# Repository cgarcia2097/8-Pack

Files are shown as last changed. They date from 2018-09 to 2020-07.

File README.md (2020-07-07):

# 8-Pack

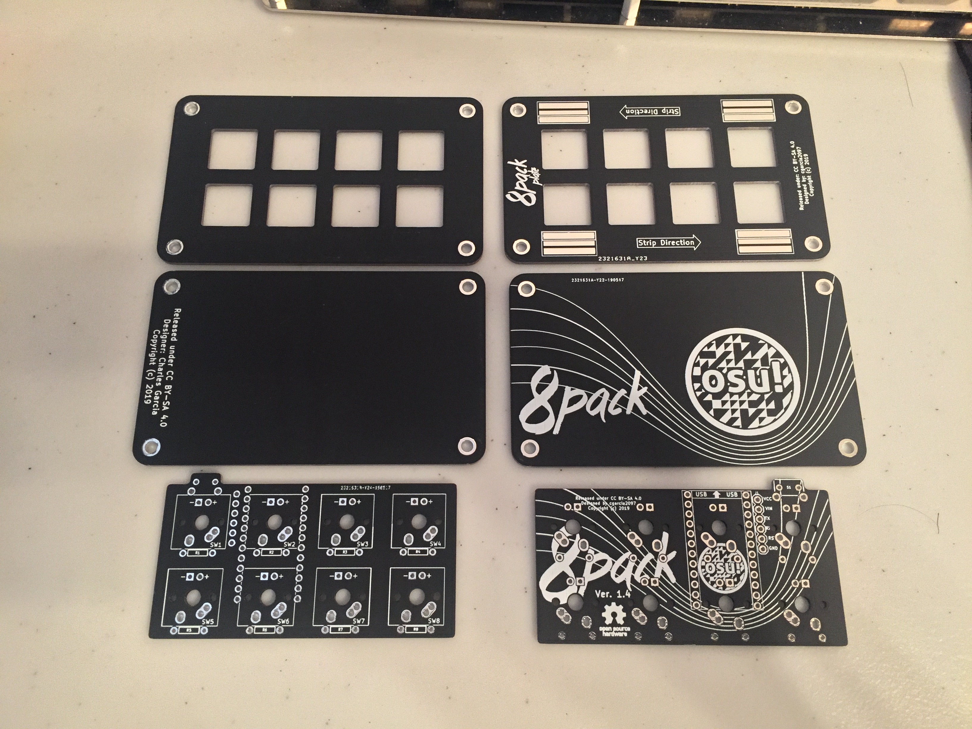
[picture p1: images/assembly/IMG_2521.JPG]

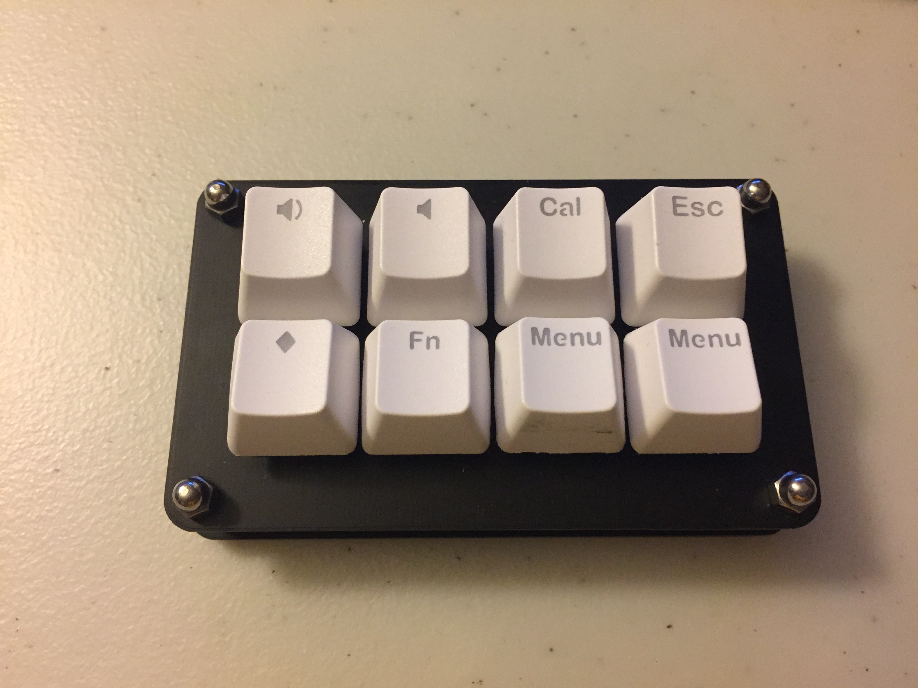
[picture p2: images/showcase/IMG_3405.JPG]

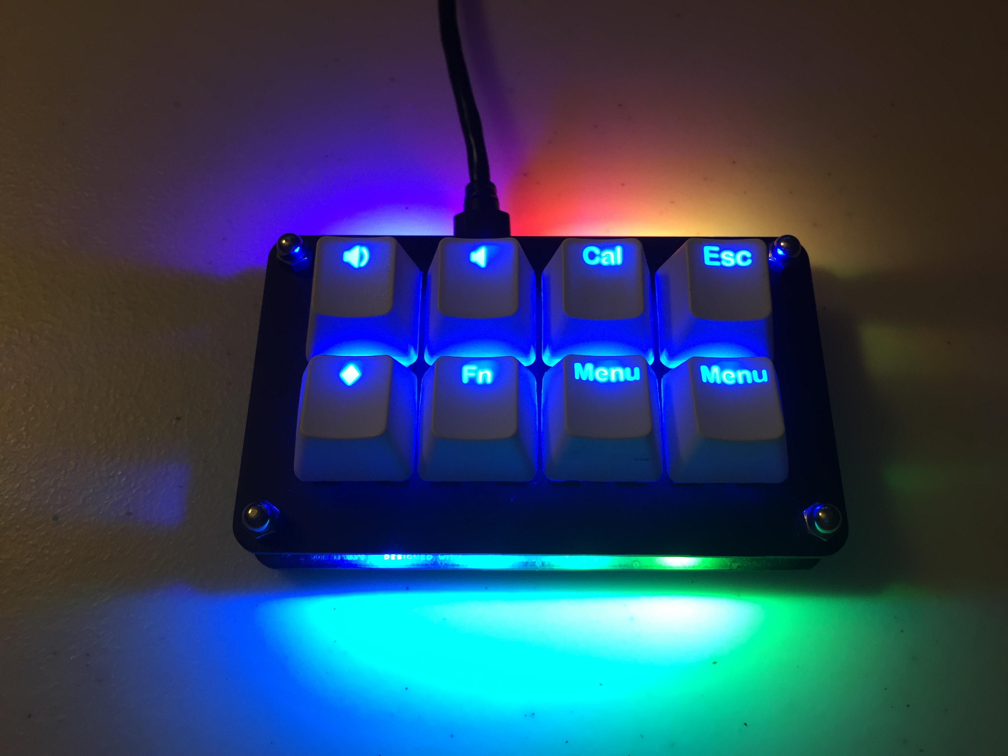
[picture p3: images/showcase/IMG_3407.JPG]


Inspired by [di0ib's Six Pack design](http://www.40percent.club/2017/04/six-pack-10.html), this keypad project is intended for me on learning how to use KiCAD by extending their design to 8 keys. Mishaps, snafus and foobars expected and incoming.

## Features

### PCB

  - 8 keys, directly connected to MCU pins
  - 8 backlight LEDs, individually addresssable
  - Powered by the Pro Micro
  - Alps or MX button support
  - Runs on a simple Arduino sketch, or optionally QMK firmware

### Plates
  - WS2812 strip underglow support, inspired by [di0db's Gherkin ALPS underglow](http://www.40percent.club/2017/08/gherkin-alps-11.html)

## Third-party firmware ports

- Official QMK port, courtesy of [gorbachev](https://github.com/gorbachev)
  - Rev. 1.1 : [Link](https://github.com/qmk/qmk_firmware/tree/master/keyboards/8pack/rev11)
  - Rev. 1.2 : [Link](https://github.com/qmk/qmk_firmware/tree/master/keyboards/8pack/rev12)

## Assembly guides

Assembly guide can be found here: [GUIDE](ASSEMBLY.md)

## Programming guides

Programming guide can be found here: [GUIDE](PROGRAMMING.md)

## Updates

Updates are posted here: [UPDATES](UPDATES.md)

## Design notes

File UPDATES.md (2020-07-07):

# Update 07/06/2020

It's been three months since the last update, and other projects have been on my mind lately. I am updating this repo as a change of pace, and here's the recent set of updates:

## Added to the repo
* Updated [programming guide](./ASSEMBLY.md)
* Added [more images](./images/showcase/)
* Updated [README](./README.md) page

## TBD
* QMK port for Rev. 1.4 - 1.5
* Choosing a mainline 8pack revision, since maintaining all other revisions seem redundant

# Update 04/02/2020

Whew, it's been almost a year. Finally got back into updating the repos as usual

## Added to the repo
* Updated [assembly guide](./ASSEMBLY.md)
* Updated directory structure for code, keypad and plate files

## Removed from the repo
* Redundant images and links
* KiCAD symbols and footprints (To be released as a seperate repository)
* Old assembly guide

## TODO
* Updated programming guide
* Ordering guide

# Update 04/20/2019
Did some repo cleaning and added Ver. 1.2 of the keypad PCB. I am currently considering creating seperate directories for the plate and keypad PCBs sice they both have their own revisions. I have uploaded assembly images involving the Ver. 1.2 PCB, and will be added to the assembly guide.

TODO:
* Seperate keypad, plate and source code directories
* Fix the keypad libraries uploaded
* Complete the assembly guide
* Complete programming guide

# Update 04/17/2019
I have created a skeleton guide for assembling the 8pack. The order of steps are important since backtracking the steps requires knowledge of desoldering. The guide itself is still a WIP.

Current assembly guide: ASSEMBLY GUIDE

# Update 03/29/2019
Thought I would try doing PCB plates for the keypad. So I whipped up a quick design on KiCAD that integrates LED strips facing downwards from the PCB. 

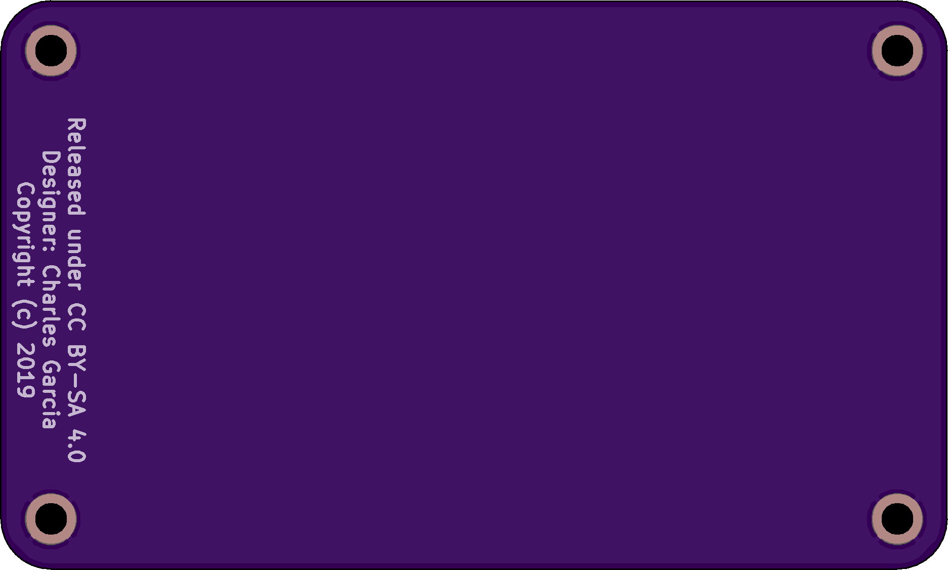
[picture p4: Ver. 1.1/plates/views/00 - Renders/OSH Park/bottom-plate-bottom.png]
bottom-plate-bottom

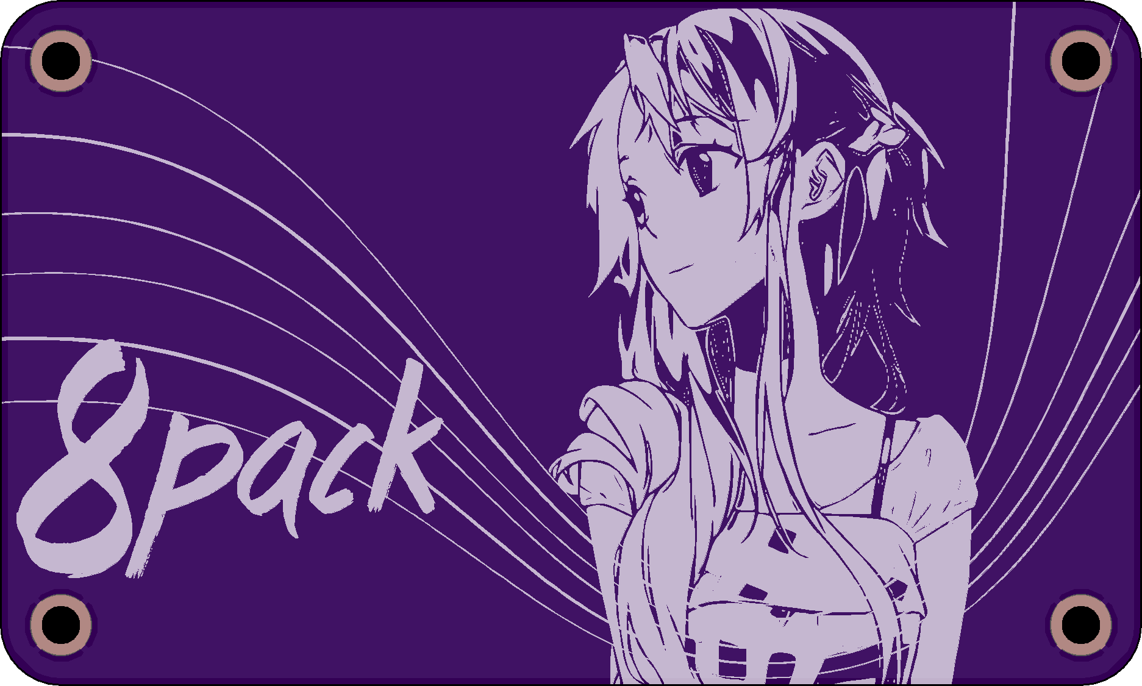
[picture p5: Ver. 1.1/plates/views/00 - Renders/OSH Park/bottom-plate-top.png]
bottom-plate-top

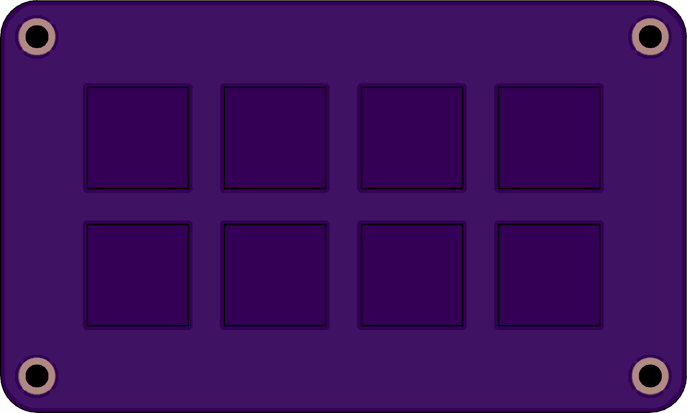
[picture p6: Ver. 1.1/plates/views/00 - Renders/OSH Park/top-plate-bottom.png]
top-plate-bottom

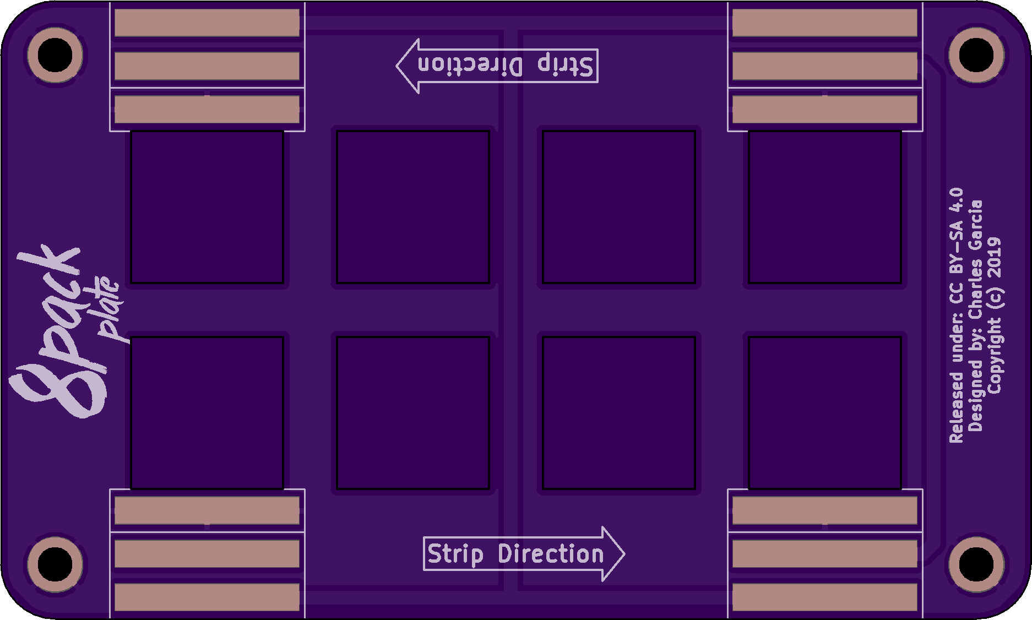
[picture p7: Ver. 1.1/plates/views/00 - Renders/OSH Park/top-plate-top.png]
top-plate-top


The plates have arrived from JLCPCB, and the results are as follows:

* The square cutouts are rounded, but still allow for the fitting of Cherry-style switches. I used di0ib's Six-Pack plate as inspiration.

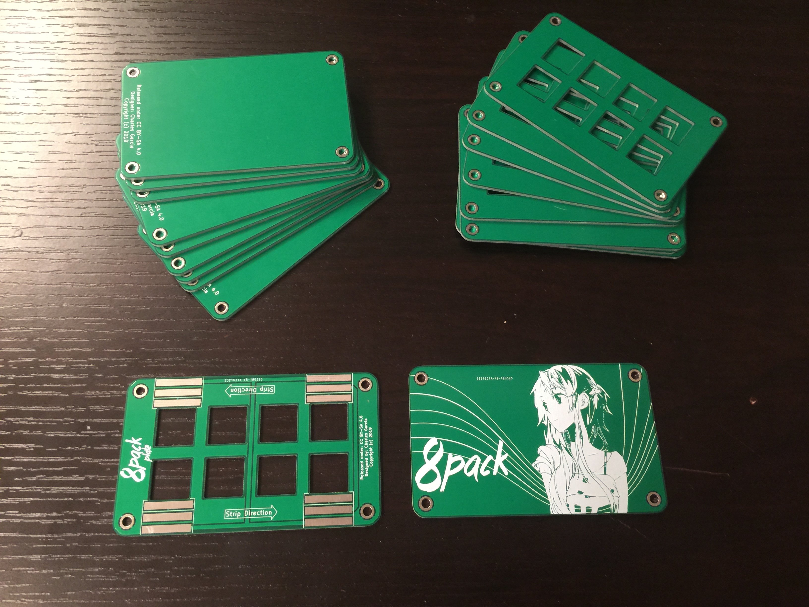
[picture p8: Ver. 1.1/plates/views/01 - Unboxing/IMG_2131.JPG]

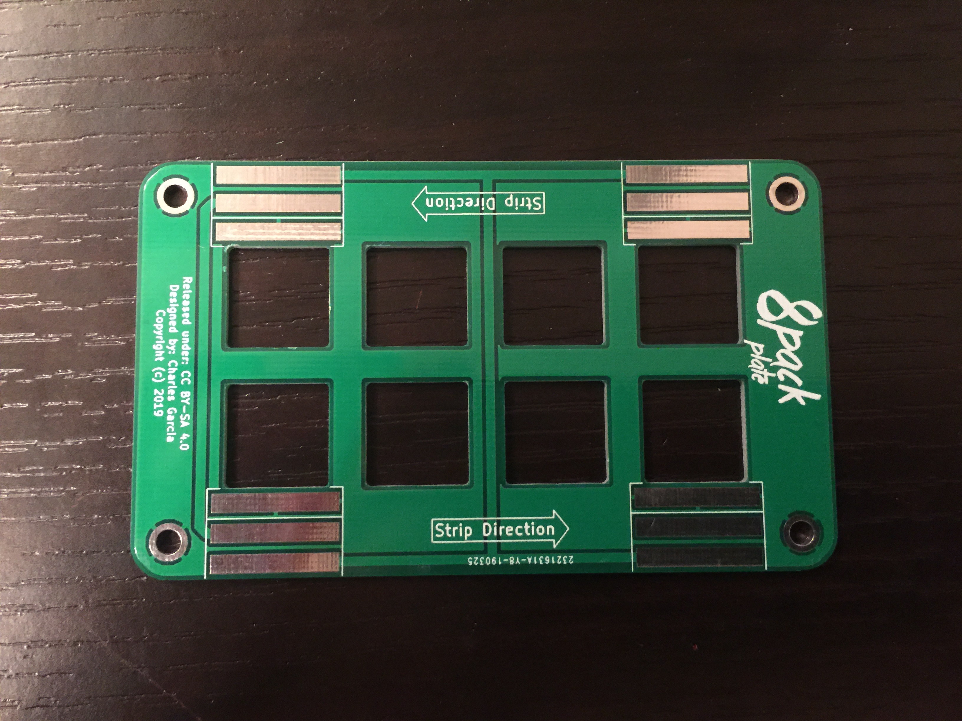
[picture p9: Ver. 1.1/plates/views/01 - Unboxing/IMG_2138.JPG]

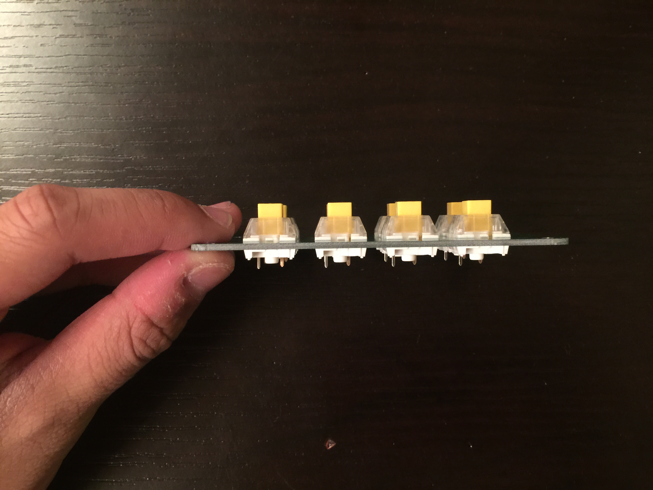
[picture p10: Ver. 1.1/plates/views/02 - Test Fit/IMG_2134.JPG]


* The LED pads are misaligned with the LED strip I used. Guess I need to re-measure those LED pads once more so they are easier to solder together. In the meantime, I used an old-fashioned solder bridge to do the job. In the end the lighting circuit worked.

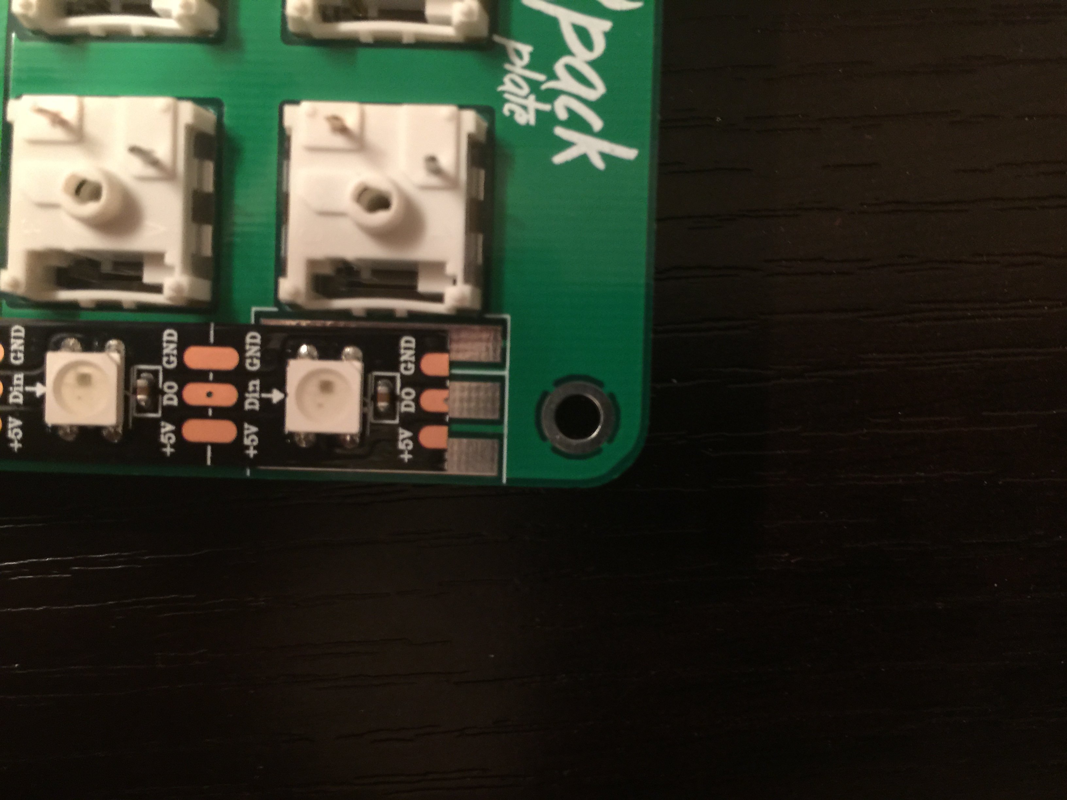
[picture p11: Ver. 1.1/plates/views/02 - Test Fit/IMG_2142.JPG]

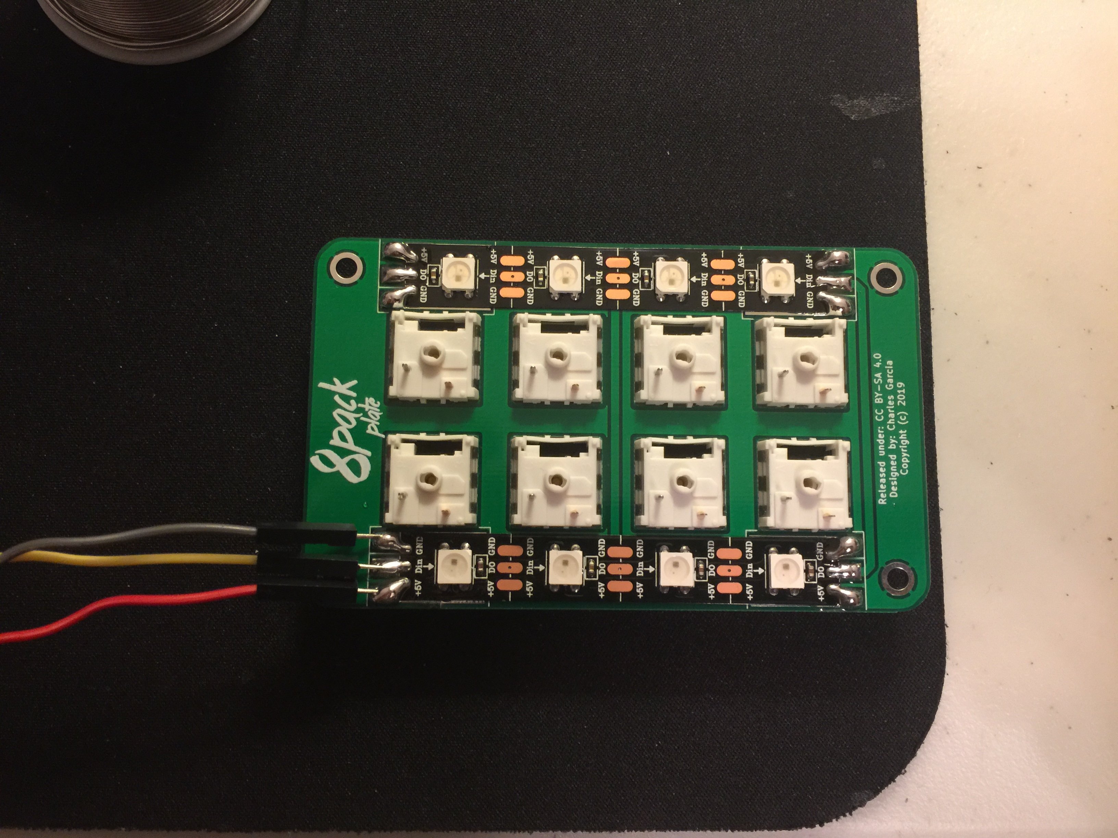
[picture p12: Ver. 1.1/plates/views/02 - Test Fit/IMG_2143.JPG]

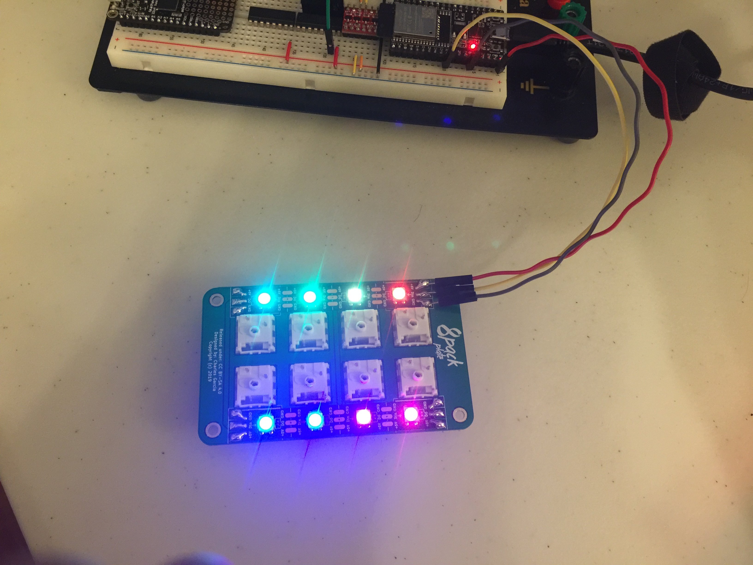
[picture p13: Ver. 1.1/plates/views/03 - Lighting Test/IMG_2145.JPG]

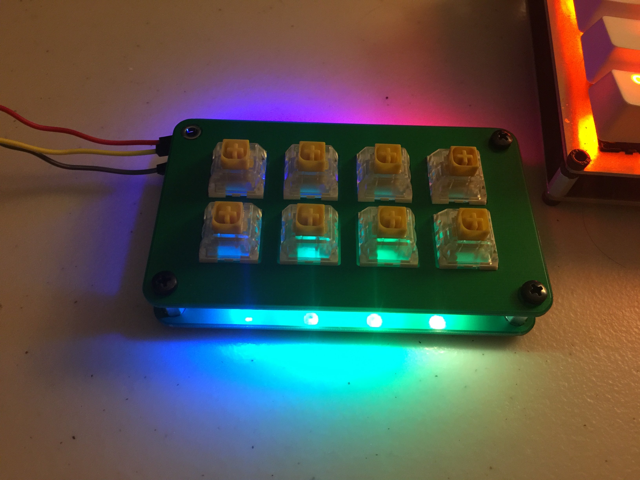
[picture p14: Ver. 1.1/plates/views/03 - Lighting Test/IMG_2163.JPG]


* PCB material is tough. No wonder other KBDers use them in budget builds and kits.

### More images in this link Please enjoy :)

TODO: 
* Assembly guides
* Post photos and format accordingly
* Firmware guides
* Other repo cleanup

# Update 02/20/2018
I decided to take a detour and learn KiCAD for version 1.1 of the PCB. As such, the design files uploaded are now in the KiCAD format. Gerbers, PCB files and schematics are now available for use and scrutiny.

The PCBs have arrived from JLCPCB and tested with a multimeter. Arduino sketch has also been tested on the board to verify basic funtionality.

Fixes:
* RESET and GND are no longer shorted. 
* The Pro Micro has been re-oriented so that the user no longer is required to use sockets to elevate it. Simple male headers will suffice

To-do:
* Assembly/Programming guide
* Upload footage of assembly and programming guide.

## Photos
#### Front
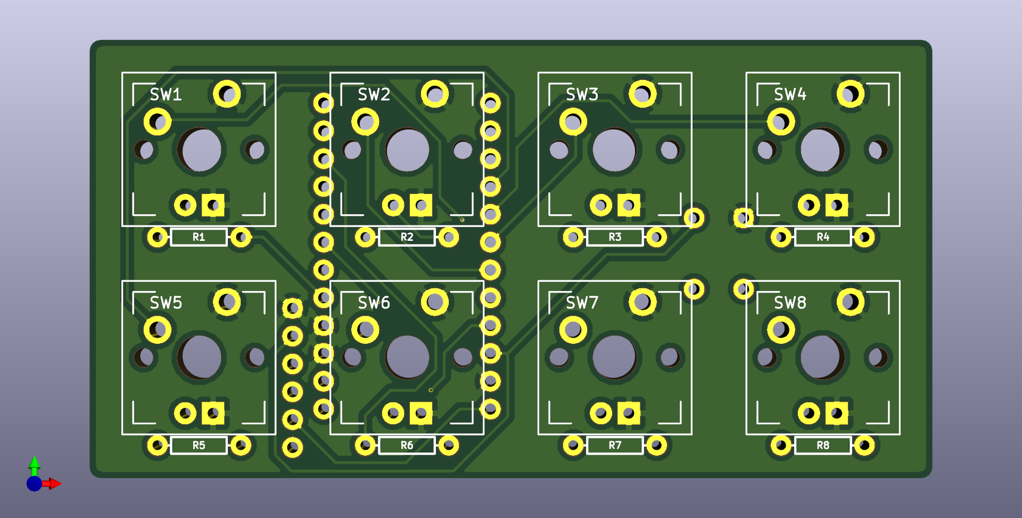
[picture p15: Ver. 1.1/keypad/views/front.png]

#### Back
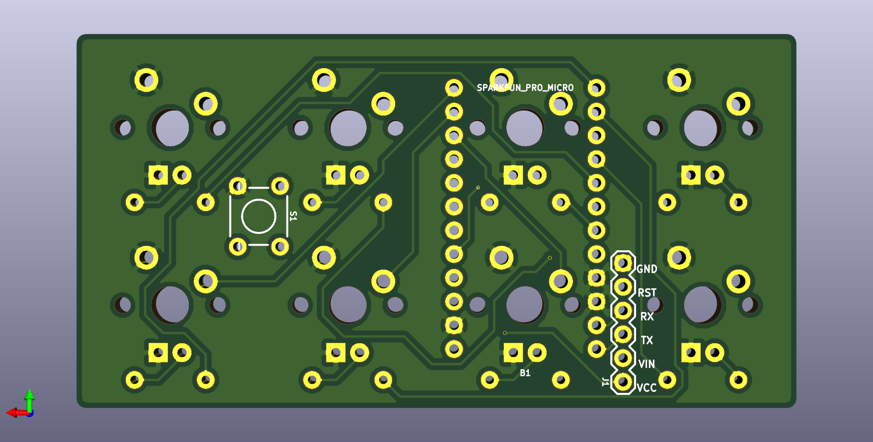
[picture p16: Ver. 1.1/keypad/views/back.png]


# Update 09/27/2018
First batch of PCBs have arrived from Aisler. I am happy to report that the PCBs are of high quality, as well as my footprints being correct and accurate. The parts fit together like a charm. 

Unfortunately, the existing gerbers on the repo exhibit issues discussed below:

- RESET and GND are shorted for some reason. Verified with a continuity check for the entire batch. Must be my fault since they are short for all three. Just don't connect anything to the RST header on the Pro Micro, and it should work.

- The USB port on the Pro Micro touches switch #7's contacts, and interferes with the operation. Current workaround is to use a machine socket to hold the Pro Micro in place. See di0ib's use of sockets here: http://www.40percent.club/2017/04/six-pack-10.html

Otherwise I am happy to report that the keyboard is mostly functional and ready to rock some Arduino code. Will be posting footage on my youtube channel when time permits.

# Some info
- Key Unit Size: 19 mm 

###### Board
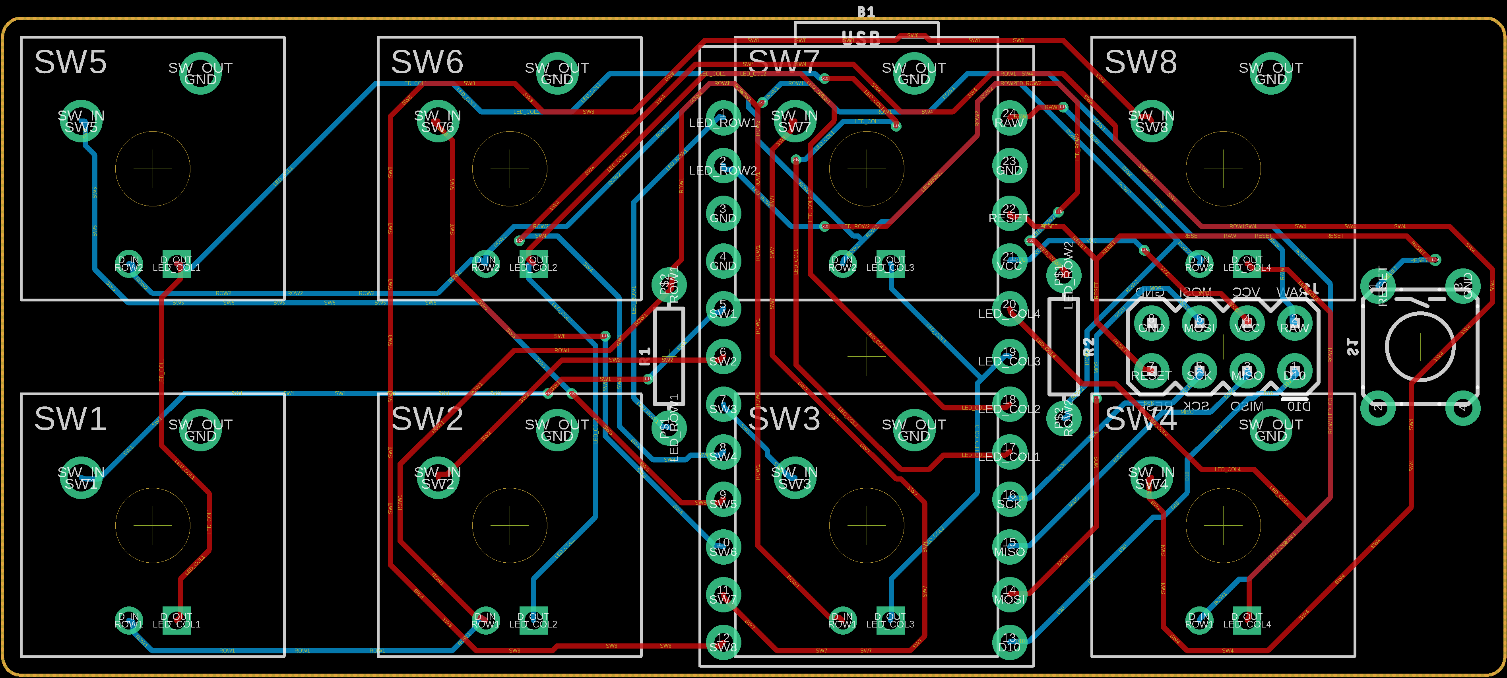
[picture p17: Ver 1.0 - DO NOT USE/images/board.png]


###### Schematic


If using swillkb's plate editor don't forget to set the unit size to 19 mm. Otherwise, the centers of each switch are 19 mm apart

# Photos
###### Lighting
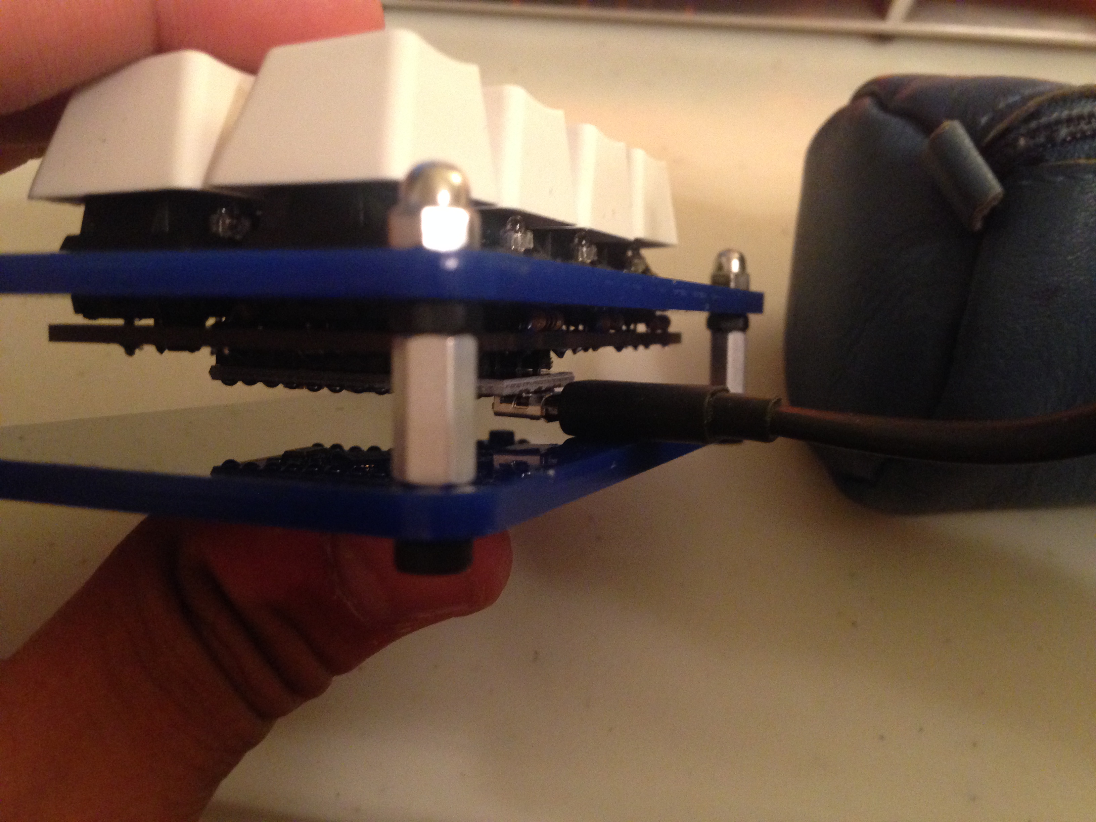
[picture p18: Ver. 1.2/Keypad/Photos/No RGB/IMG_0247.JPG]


###### Pro Micro Attached


###### Back Side


###### Front Side


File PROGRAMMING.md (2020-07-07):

# Programming Guide for 8pack
This guide will go through the method of flashing default firmware into the 8pack using the Arduino environment. Other methods are under consideration at the moment. 

### 1 - Download the required software

- Download and install the Arduino IDE from the Arduino website. ( [Link](https://www.arduino.cc/en/Main/Software) )
- Click `Install` through all the driver download prompts.
- Click `Close` when finished.

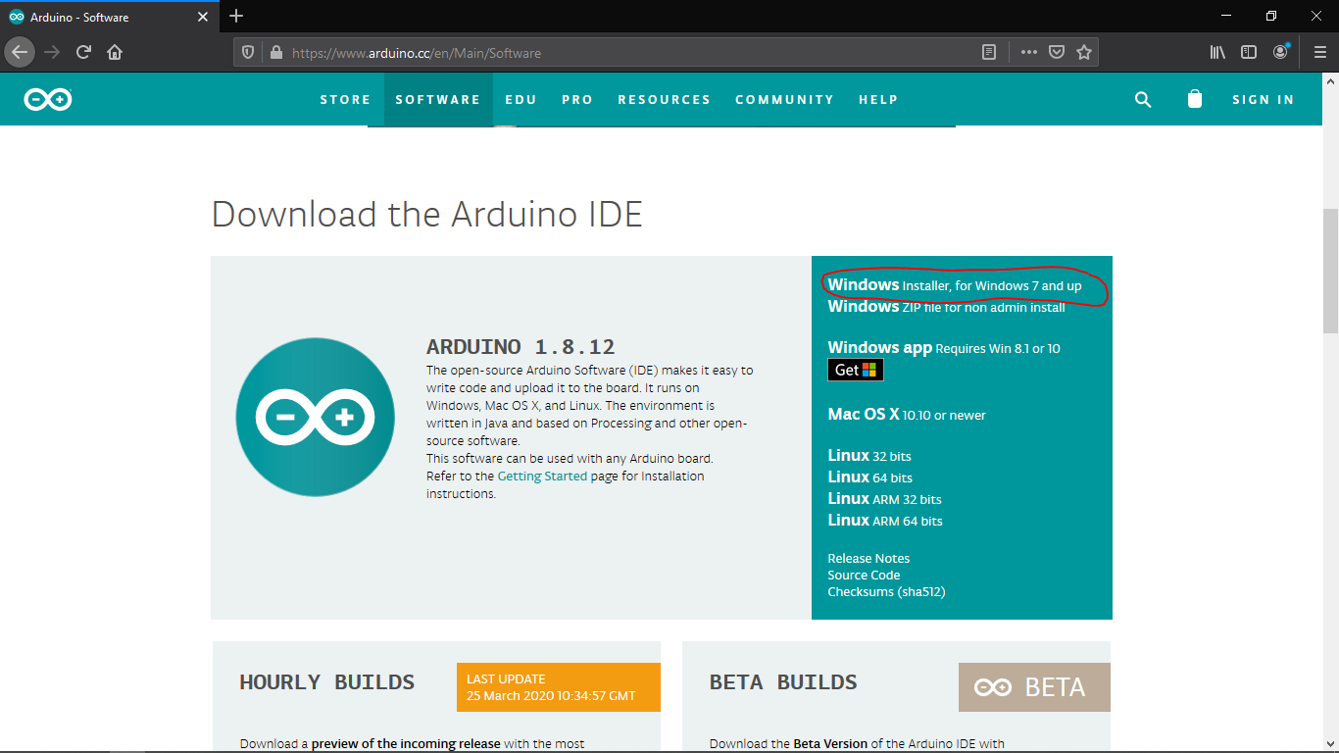
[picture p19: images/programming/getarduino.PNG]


### 2 - Get the code from the repository

- Download and unpack the project: https://github.com/cgarcia2097/8-Pack/archive/master.zip. 
- Inside Arduino, click `File`->`Open`
  
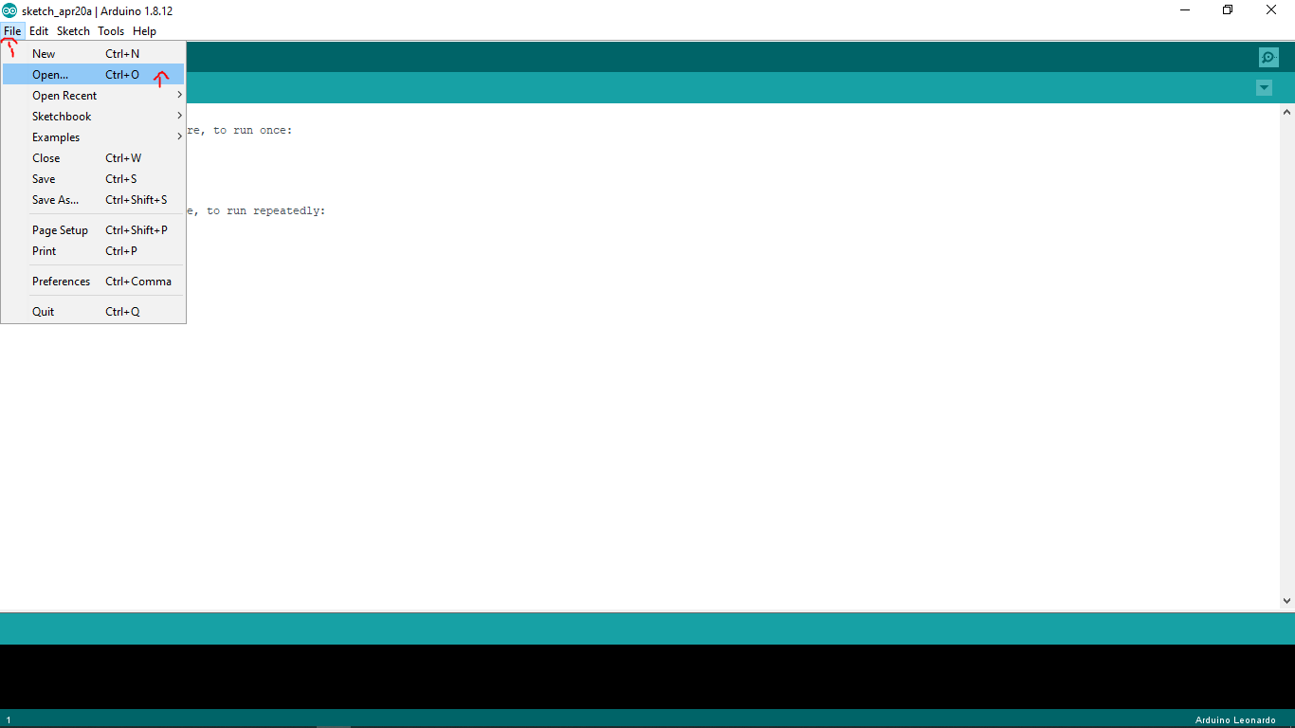
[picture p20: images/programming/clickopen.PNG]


- Find and open the newly-extracted `8-Pack` folder in Arduino
  
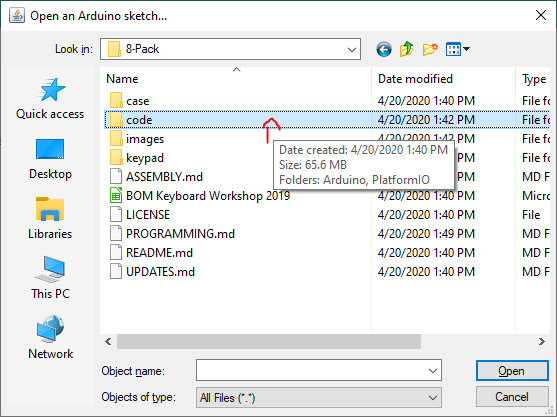
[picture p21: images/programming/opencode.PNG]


- Inside the folder, go to `code`->`Arduino`->`8pack`->`8pack.ino`.

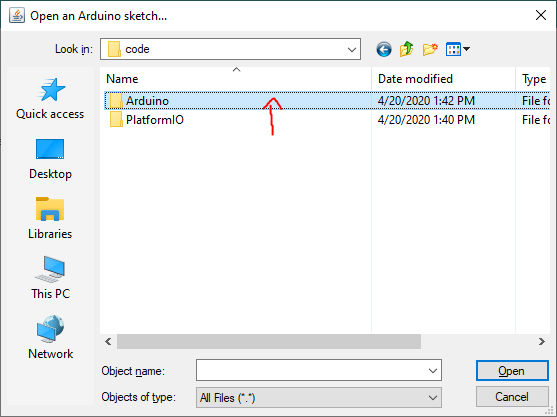
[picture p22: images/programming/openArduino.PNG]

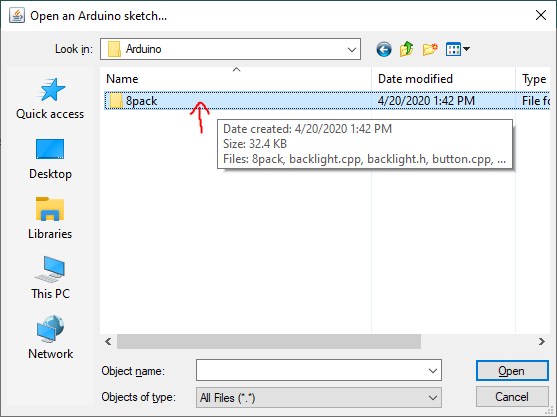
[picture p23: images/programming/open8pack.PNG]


- Open `8pack.ino`

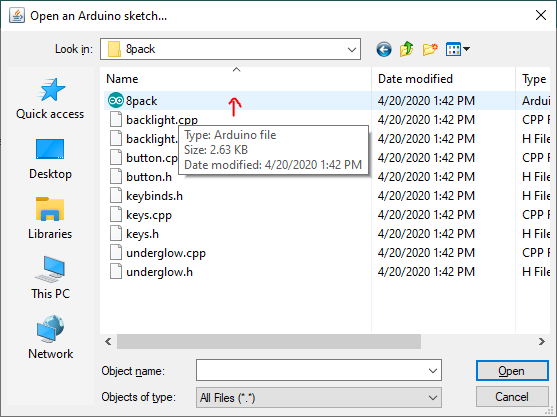
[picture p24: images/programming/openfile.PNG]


### 3 - Setting up the flashing environment

The 8pack requires a specific environment at the moment to reprogram it, as no app exists at the moment.

#### 3.1 - Installing the Libraries

Once installed, download the required libraries by clicking `Sketch`->`Include Library`->`Manage Libraries` and install these libraries:
  - Adafruit Neopixel
  - Bounce2

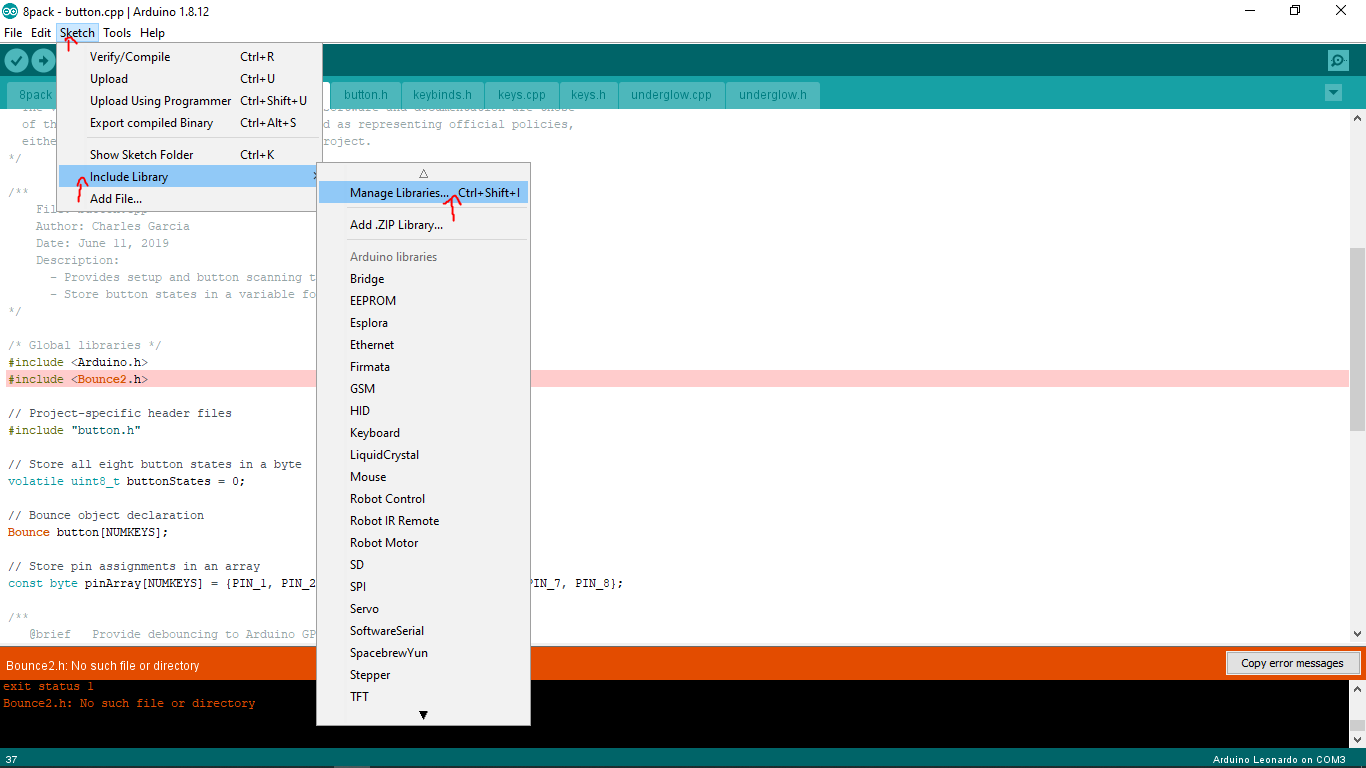
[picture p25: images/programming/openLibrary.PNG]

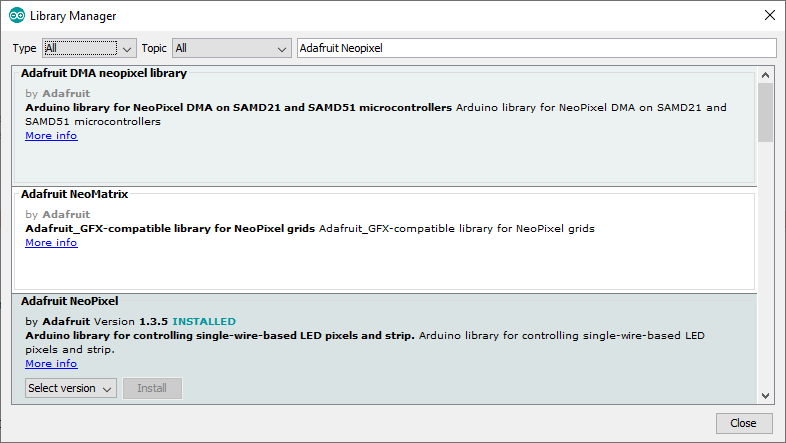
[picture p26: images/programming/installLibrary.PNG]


#### 3.2 - Programming for the Pro Micro

To set the environment to program for a Pro Micro, click `Tools`->`Board`->`Arduino Leonardo`. 

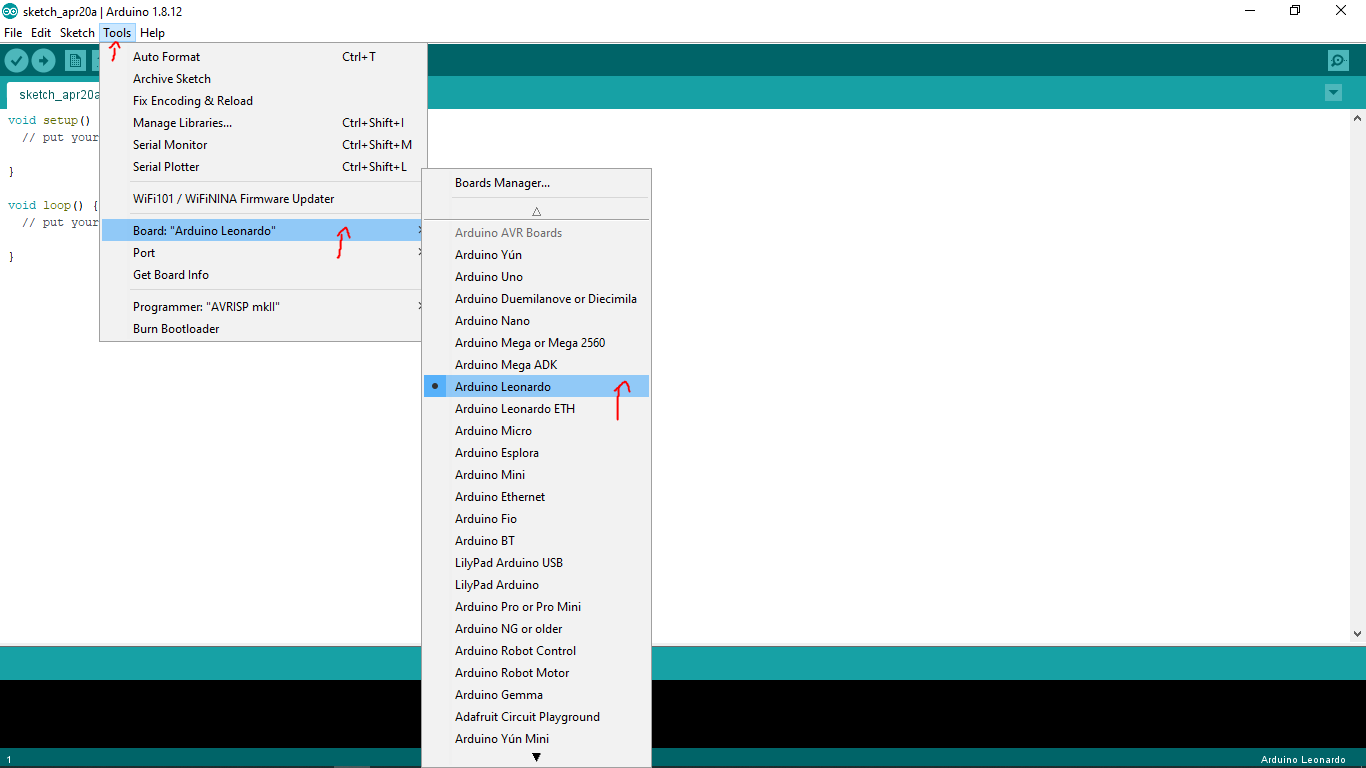
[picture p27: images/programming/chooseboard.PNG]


While the Pro Micro has its own [installation guide](https://learn.sparkfun.com/tutorials/pro-micro--fio-v3-hookup-guide/all), it seems to share the same pin labels as the Arduino Leonardo. Choosing the Leonardo allows us to skip the hassle of setting up the Pro Micro manually, but may be subject to change later down the line as Sparkfun may change their design.

### 4 - Editing the keybinds

Click over to the tabs and select `keybinds.h`



You will see a large block of text that looks like this:
``` 
const unsigned char macroArray[NUMKEYS][HID_USB_LIMIT] = {
  {KEY_ESC, STOP_CODE, STOP_CODE, STOP_CODE, STOP_CODE, STOP_CODE},
  {'d', STOP_CODE, STOP_CODE, STOP_CODE, STOP_CODE, STOP_CODE},
  {'s', STOP_CODE, STOP_CODE, STOP_CODE, STOP_CODE, STOP_CODE},
  {'a', STOP_CODE, STOP_CODE, STOP_CODE, STOP_CODE, STOP_CODE},
  {'v', STOP_CODE, STOP_CODE, STOP_CODE, STOP_CODE, STOP_CODE},
  {'c', STOP_CODE, STOP_CODE, STOP_CODE, STOP_CODE, STOP_CODE},
  {'x', STOP_CODE, STOP_CODE, STOP_CODE, STOP_CODE, STOP_CODE},
  {'z', STOP_CODE, STOP_CODE, STOP_CODE, STOP_CODE, STOP_CODE},
};
```



Each row starting from starting underneath `const unsigned char macroArray[]` corresponds to a button on the keypad.

What the keypad does is iterate through each row pressing and releasing (for when button is pressed or released) each key up until the `STOP_CODE` marker appears. This allows us to do a single press or multiple simultaneous keypresses per button.

Let's go through some examples.

- If you want to press the `Escape` key on button 1, the first row should look like:

  `{KEY_ESC, STOP_CODE, STOP_CODE, STOP_CODE, STOP_CODE, STOP_CODE},`

- If you're a little macro heavy and wanna type a six-letter word on button 5, the fifth row should look like:

  `{'m', 'a', 'n', 'n', 'e', 'r'},`

- If you like your Copy and Paste functionalities, your chosen two rows would look like this

  `{KEY_LEFT_CTRL, 'c', STOP_CODE, STOP_CODE, STOP_CODE, STOP_CODE},`

  `{KEY_LEFT_CTRL, 'z', STOP_CODE, STOP_CODE, STOP_CODE, STOP_CODE},`

Letters, numbers and symbols are typed in single quotes, while modifiers like CTRL and SHIFT must use the defined macros here: https://www.arduino.cc/en/Reference/KeyboardModifiers

### 5 - Compiling and uploading the code

- Plug the keypad into your PC.
- Click `Tools`->`Ports` and select the port with (Arduino/Genuino) beside the port name




- Click `Verify` to compile your code




- Click `Upload` to upload your code




### Testing out the keypad bindings
Open your text editor of choice and give the keys some quick presses and see if the desired keys are being shown on screen. 



### TMK/QMK support
A third-party has created a QMK port of my keypad, which can be found here: https://github.com/qmk/qmk_firmware/tree/master/keyboards/8pack

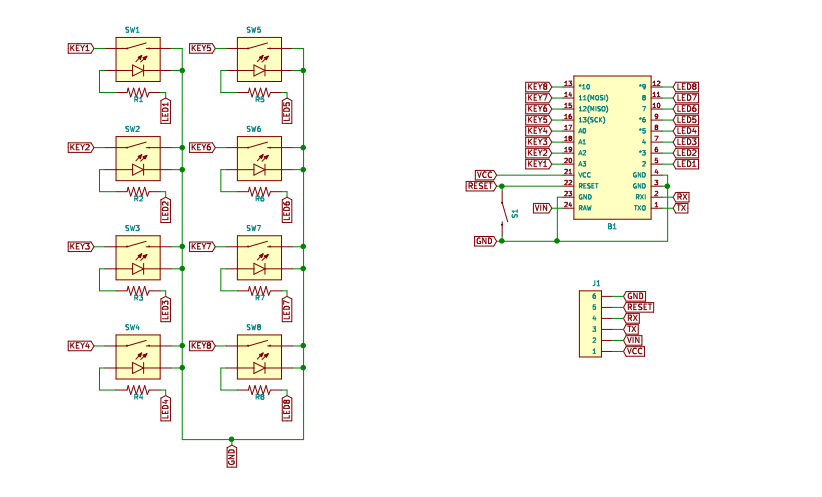
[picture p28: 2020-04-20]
images/schematic.png

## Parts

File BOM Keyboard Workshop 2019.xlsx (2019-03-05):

Part | Cost (before shipping) | Link | Unit Qty.
Pro Micro | 8.99 | https://www.amazon.ca/Pro-Micro-Atmega32u4-Arduino-Development/dp/B01N4TVIQX | 1
PCB | 2.65 | https://jlcpcb.com/quote | 10
MX-Compatible Switch | 3.18 | https://novelkeys.xyz/products/gateron-switches?variant=19441344970845 | 10
160 ohm resistor | 4.84 | https://www.digikey.ca/product-detail/en/stackpole-electronics-inc/CF14JT160R/CF14JT160RCT-ND/1830331 | 250
LED | 20 | http://www.maxkeyboard.com/max-keyboard-orange-3mm-flangeless-replacement-led-for-backlit-mechanical-keyboard-110-pcs.html | 100
Blank Keycaps | 1.32 | http://www.maxkeyboard.com/row-2-size-1x1-cherry-mx-keycap-r2-1x1.html | 1
#6 x 1/4" screws | 1.18 | https://www.homedepot.com/p/6-x-1-4-in-Phillips-Zinc-Plated-Steel-Pan-Head-Sheet-Metal-Screw-16-per-Pack-806181/204275186 | 4
Each Keyboard needs:
1 Pro Micro
8 Resistors
8 buttons
8 Keycaps
8 LEDs
1 PCB
4 Screws

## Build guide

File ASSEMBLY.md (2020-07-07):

# Assembly Guide
This doc should go over the basics of how to assemble the 8pack keypad. 

#### Prerequisites
* Basic soldering knowledge and experience (through-hole components, orientation)
* Basic electronics knowledge 

#### Terms used frequently in this guide
* __PCB/Board__ - A printed circuit board. It contains copper tracks in which multiple electronic components are connected together after soldering.
* __Through-hole__ - part of an exposed copper track where electronic components are attached and soldered.
* __Leads__ - long metal wires attached to electronic components. Usually found on simple components like resistors, keyswitches and LEDs
* __Headers__ - A type of connector used to connect components together. Male headers have exposed leads, and female headers have sockets
* __Pins__ - Connections to a microcontroller's ports, usually attached to other electronic components in order to interact with them.
* __Joint__ - the place where a component's lead intersects with a through-hole.

#### Parts in the kit:
* __Keyswitch/button__ - What the microcontroller checks to send keypresses
* __Keycap__ - What your fingers press to interact with your keypad
* __Plate__ - Where the keyswitches are mounted; also protects the electronic components from direct contact.
* __Resistor__ - Component used to protect the LEDs from burning out
* __LED__ - The lighting on the keypad 
* __Header__ - A connector used for attaching electrical components together
* __PCB__ - The board responsible for electrically connecting the keypad together
* __Microcontroller__ - The module responsible for reading the switches and flashing the LEDs. 
* __Standoffs__ - A really long nut with threads on the inside, used to fix/mount boards in place. Usually used with the appropriately-sized screw.

## Board assembly
This section delves into the assembly of the 8pack keypad, in chronological order. Order of assembly is important, as backtracking the steps requires knowledge of desoldering (a difficult process even for experienced hobbyists). There are also sub-steps in the main steps outlined above, which also need to be followed in that order.

DISCLAIMER: The photos used for this guide both show pictures from Ver 1.2 and Ver 1.4. However, the assembly guide focuses on Ver 1.4 and above

# Step 1 - Inspect the parts

Make sure all parts listed above are present.

* Main keypad components
  * 8 x keyswitches
  * 2 x headers
  * 1 x Pro Micro microcontroller board
  * 1 x right-angle pushbutton
  * 1 x top plate
  * 1 x bottom plate
  * 1 x keypad PCB
  * 4 x M3 10mm standoffs
  * 8 x M3 6mm machine screws

* Backlighting components
  * 8 x 1.8mm LEDs
  * 8 x 180 ohm resistors

* Underglow components
  * 2 x LED WS2812B strips
  * 3 x wires (one colour of each wire)

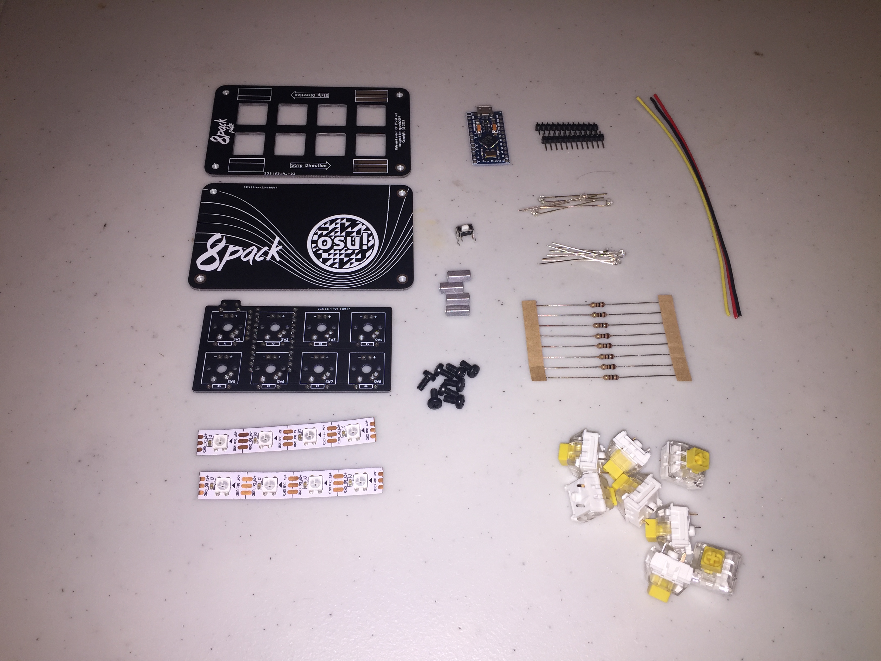
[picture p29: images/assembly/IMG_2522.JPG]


# Step 2 - Assemble top plate

## Step 2.1 - Add the optional underglow lighting - Skip if unneeded

### Step 2.1.1
Peel the cover from the LED strip backside to reveal the adhesive layer

### Step 2.1.2
Align the LED strip pads with the solder pads on the top plate. Make sure that the strip is pointing at the same direction as the top plate, and leave pad space on both ends.

Hint: GND should be aligned along the bold box, and the black line on the strip should align with the midsection of the board.

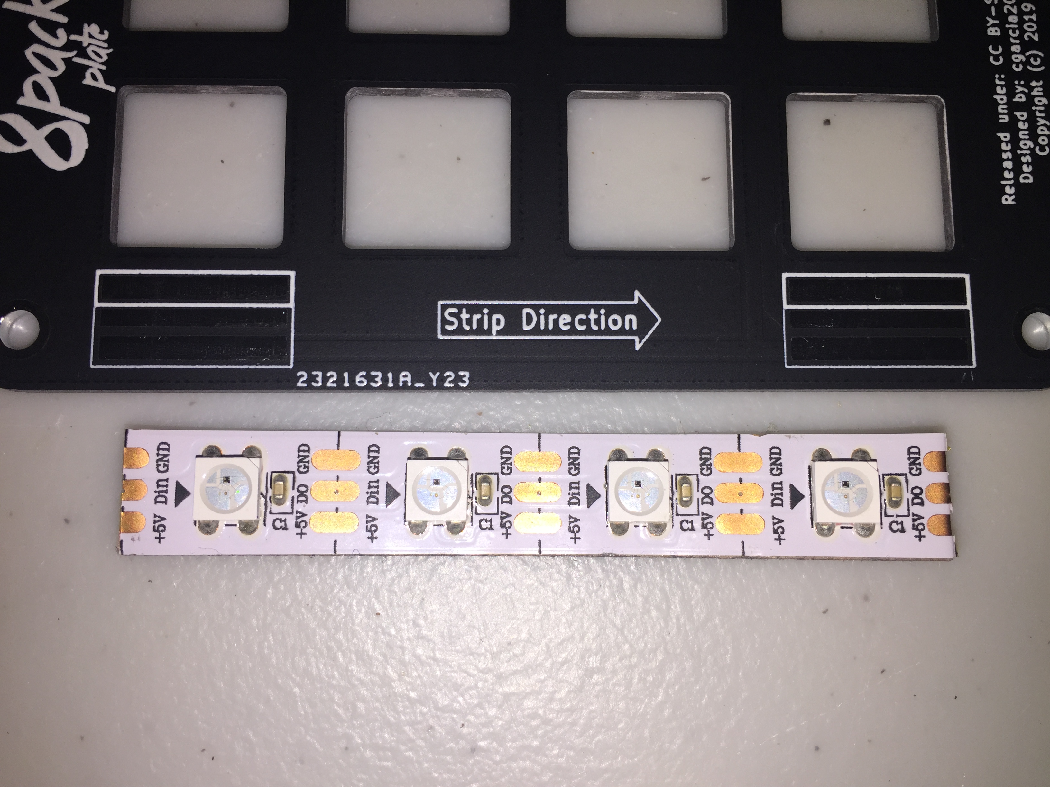
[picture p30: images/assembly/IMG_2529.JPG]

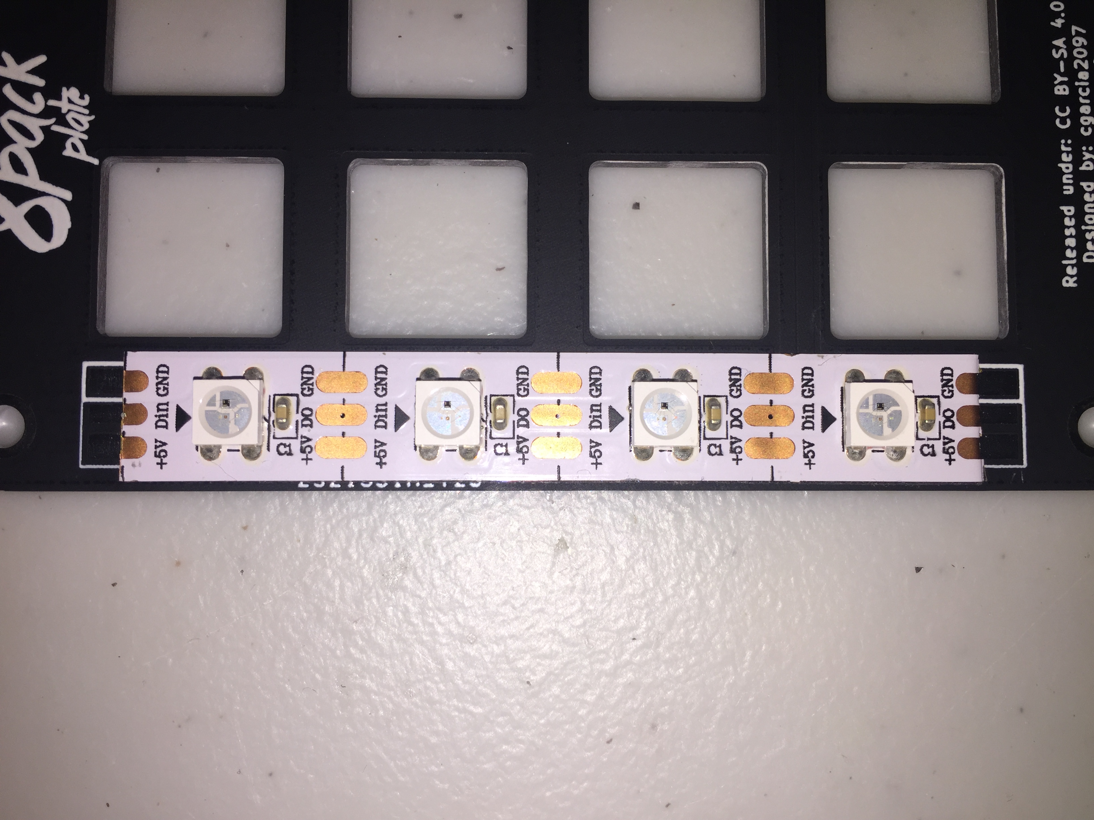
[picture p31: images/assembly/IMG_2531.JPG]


### Step 2.1.3
Bridge the solder pad between the LED strip and the top plate as shown below:

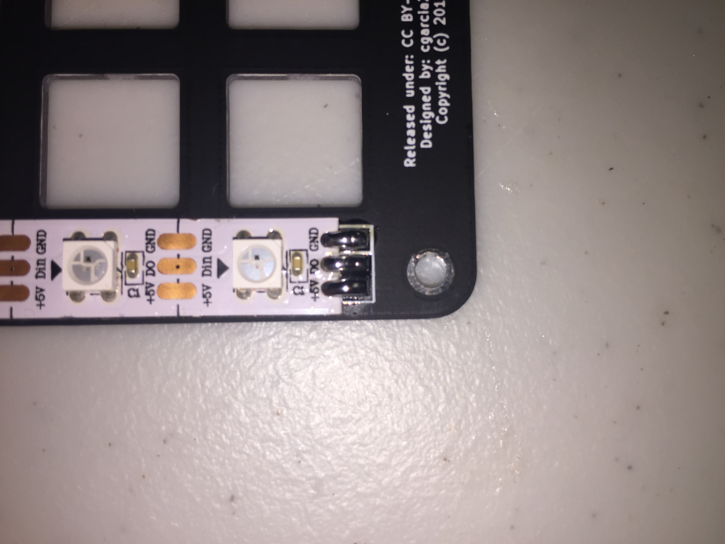
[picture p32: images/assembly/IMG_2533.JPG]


### Step 2.1.4
Repeat for the other side of the strip:

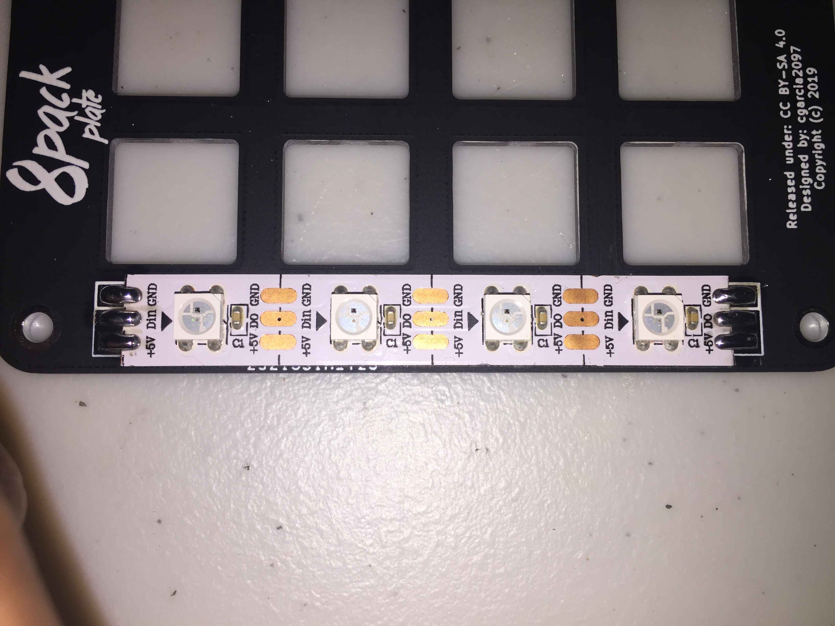
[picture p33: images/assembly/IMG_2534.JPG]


### Step 2.1.5
Now repeat the above steps for the other LED strip:

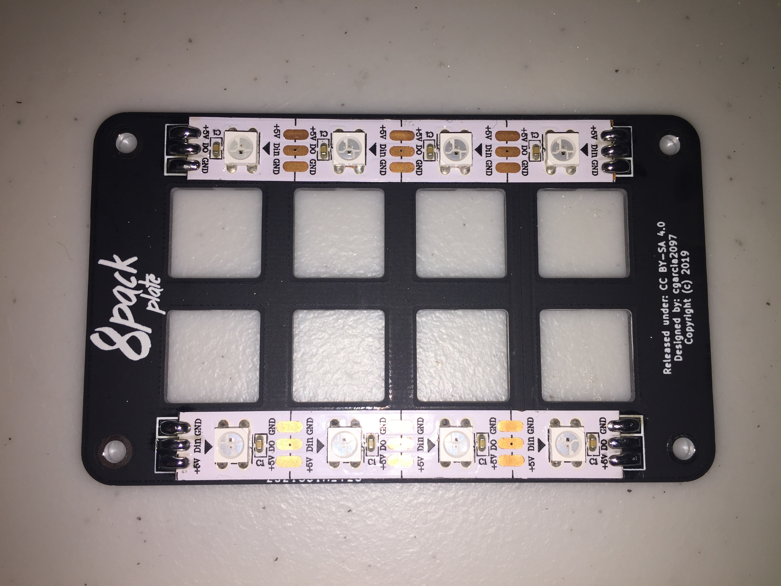
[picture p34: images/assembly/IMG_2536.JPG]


### Step 2.1.6
Now take the three wires, strip one end for each color, and solder to the pads shown below. The red wire must be soldered to +5V, the yellow to Din, and the black wire to GND.

You may also twist the wire to your heart's content. 

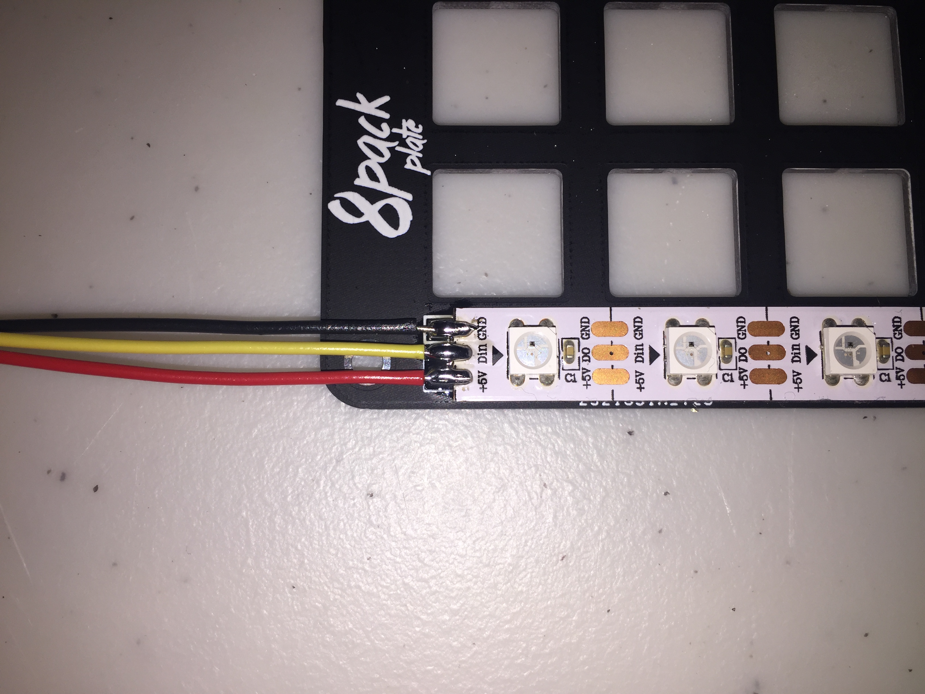
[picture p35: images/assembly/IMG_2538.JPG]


## Step 2.2 - Attach the switches

Attach the switch by pushing it through the square cutouts. Make sure that the switch pins face up and away from you, and that all the switches face in the same direction. An example is shown below:

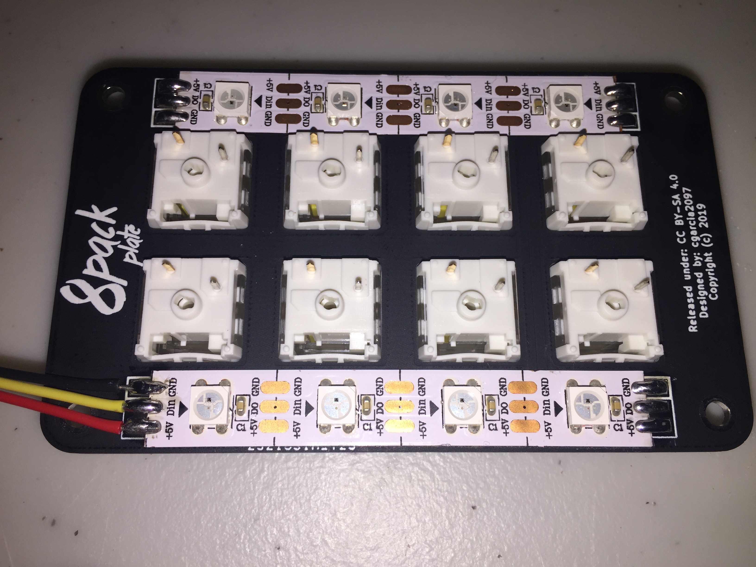
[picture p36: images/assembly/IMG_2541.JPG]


# Step 3 - Assemble the PCB

## Step 3.1 - Attach the resistors to the PCB (For backlighting use, skip if unneeded)

### Step 3.1.1
Bend each resistor to the required shape below:

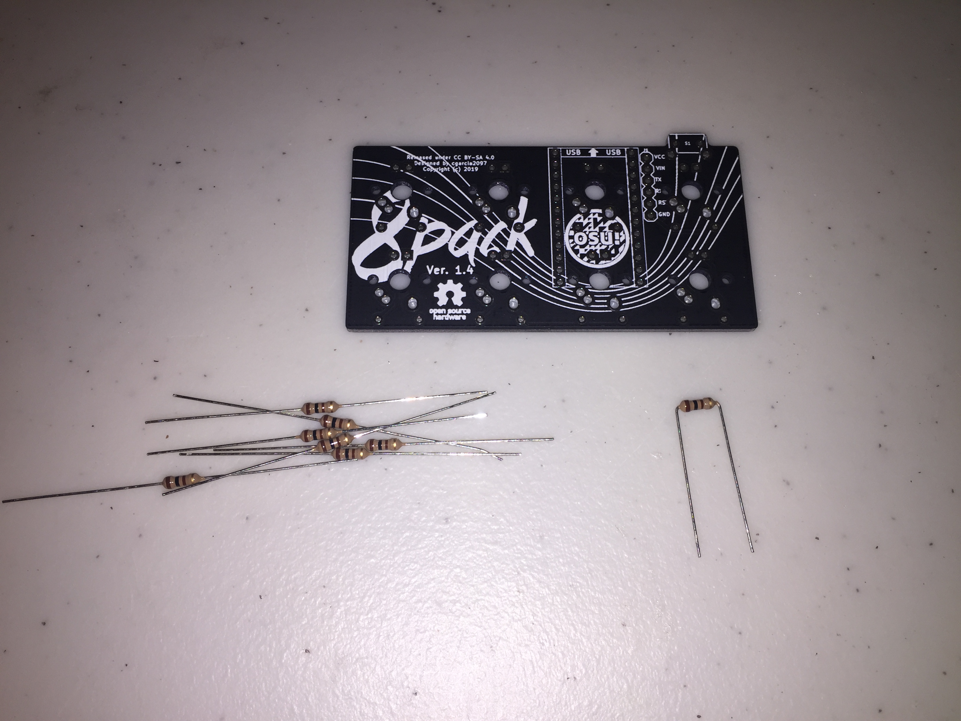
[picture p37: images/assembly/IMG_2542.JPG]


### Step 3.1.2 
Thread each resistor through the markings indicated as `R1` to `R8`. Orientation does not matter here, any direction you plug them into will work.

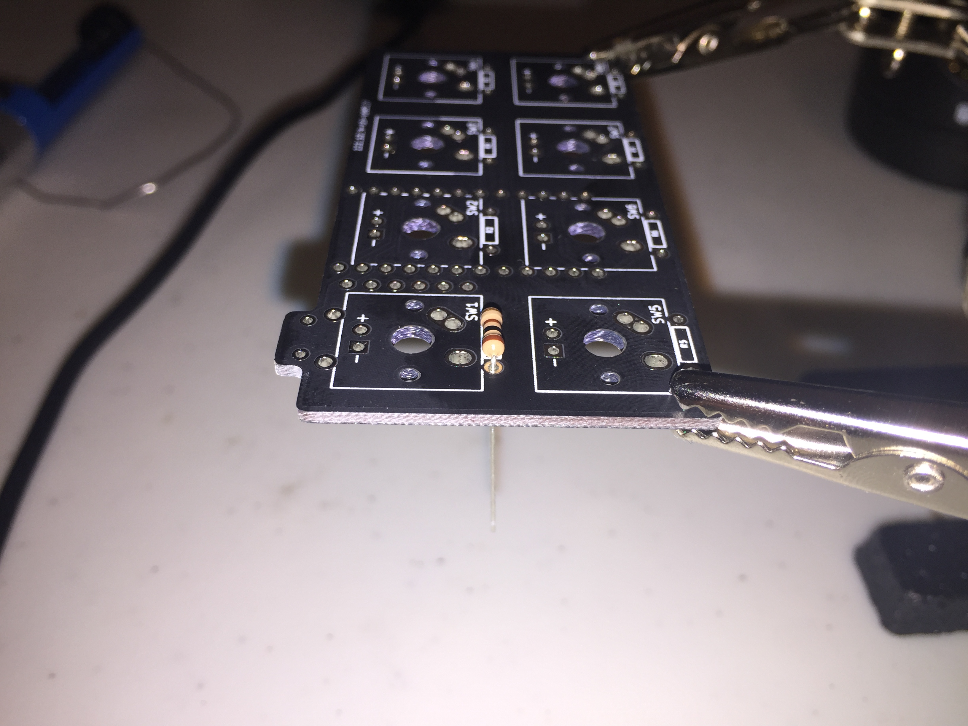
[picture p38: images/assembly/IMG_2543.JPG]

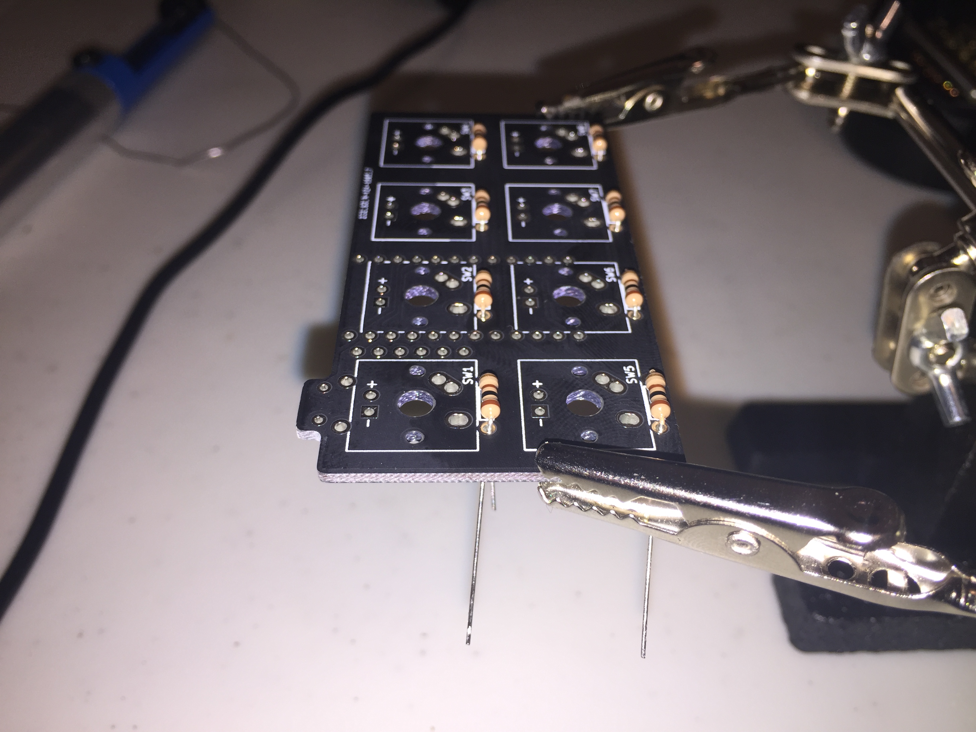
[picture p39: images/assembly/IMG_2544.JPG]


It might be useful to bend the leads outward to prevent the resistors from falling out later

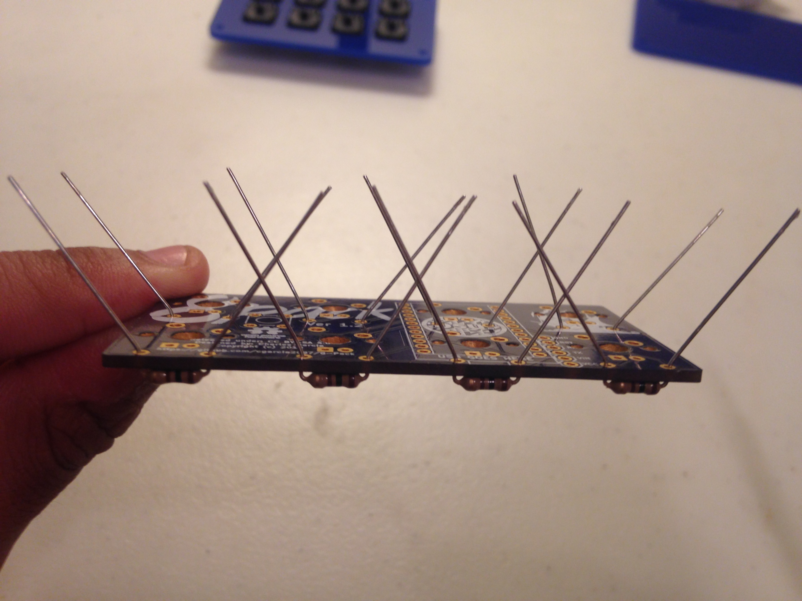
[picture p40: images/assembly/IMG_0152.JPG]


### Step 3.1.3
Solder and trim the resistor leads

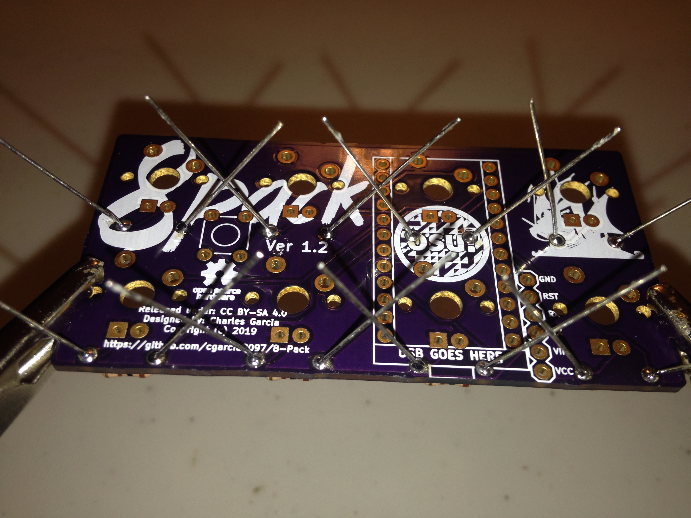
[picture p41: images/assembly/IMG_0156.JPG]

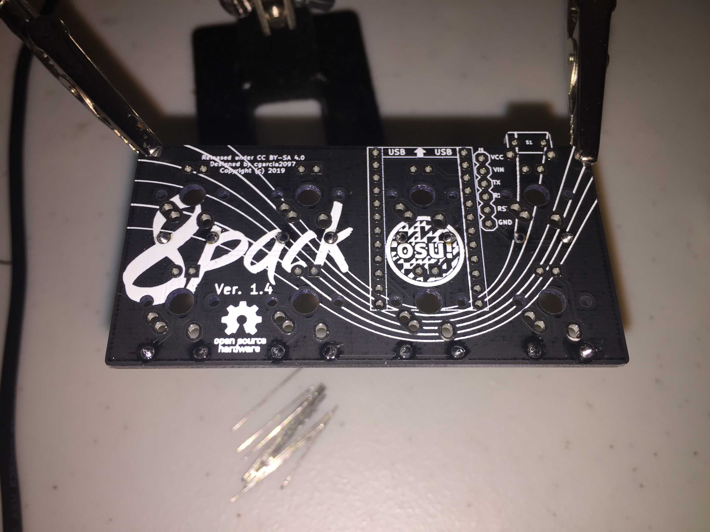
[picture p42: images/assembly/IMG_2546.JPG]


## Step 3.2 - Attach headers
This step is rather for me to explain, so I recommend [Sparkfun's guide on how to install headers](https://learn.sparkfun.com/tutorials/arduino-shields/installing-headers-assembly) to get a feel for how this step will work.

Short side goes through the hole and soldered:

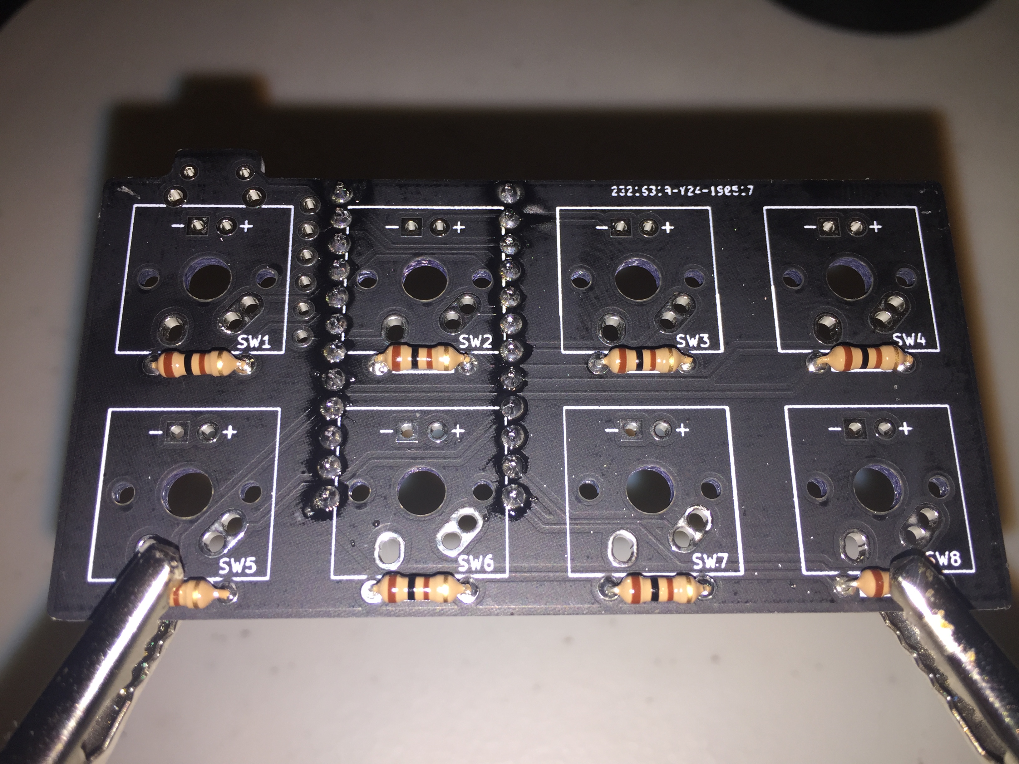
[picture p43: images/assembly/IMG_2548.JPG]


Long side faces away from it:

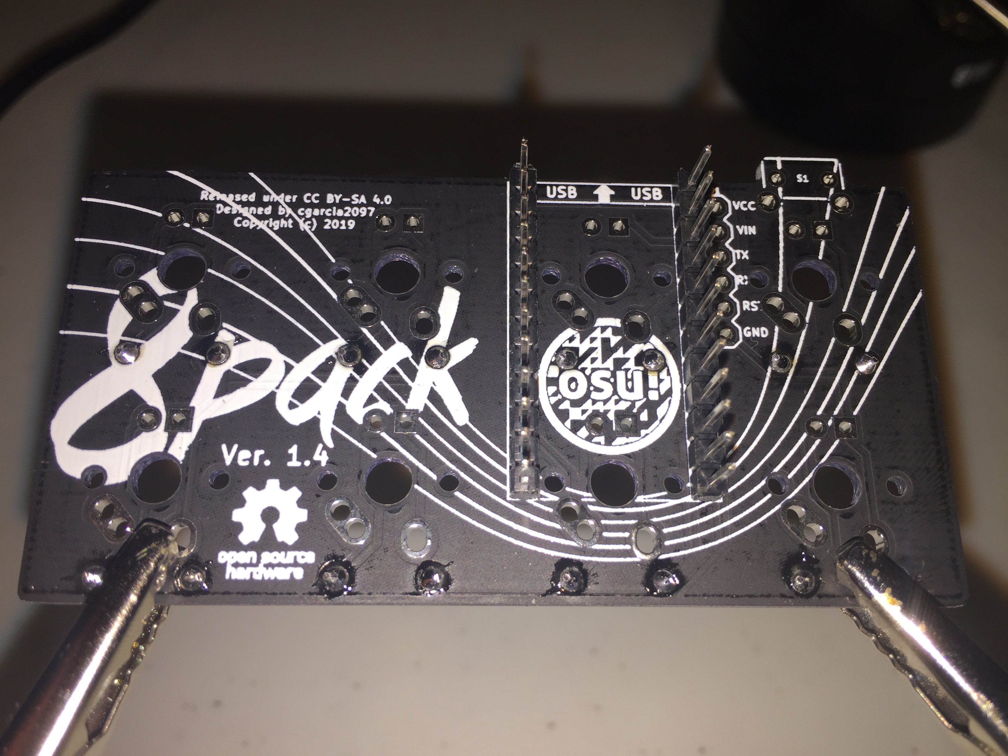
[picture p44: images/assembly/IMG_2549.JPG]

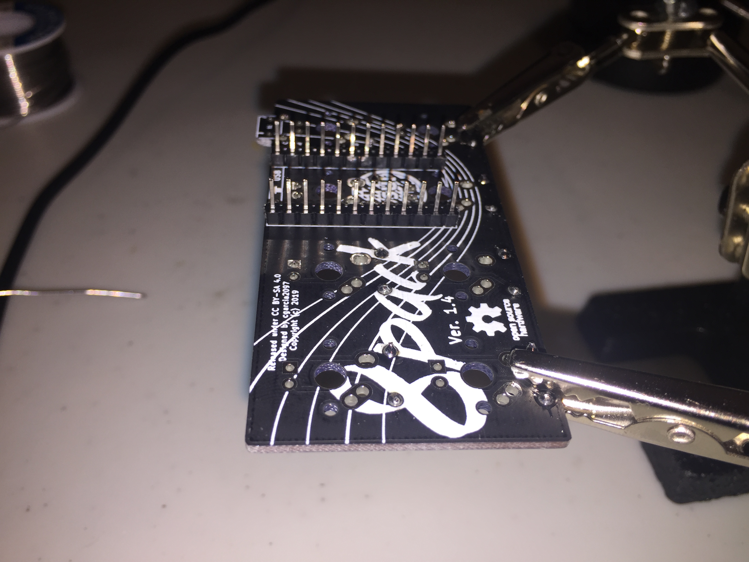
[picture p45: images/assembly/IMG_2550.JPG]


## Step 3.3 - Attach LEDs (For backlighting use, skip if unneeded)
Depending on your style of switch, the order of assembly will differ.

### Using a BOX-style switch
A BOX switch is characterized by a cross pattern inside a box, as shown here:

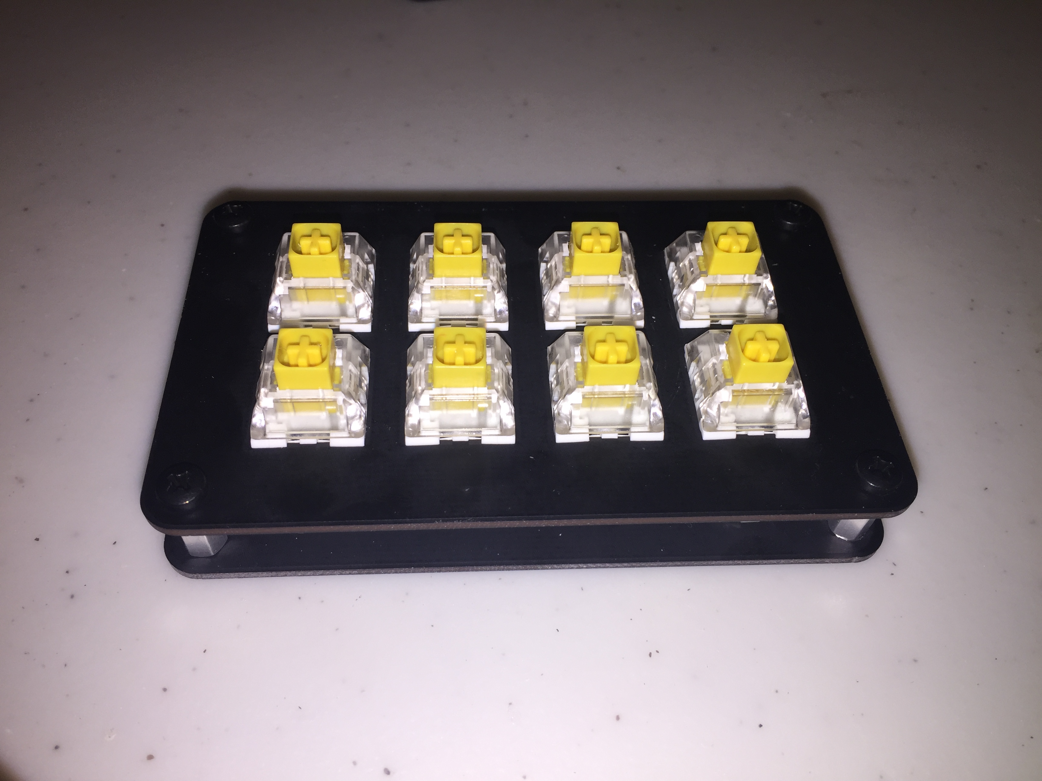
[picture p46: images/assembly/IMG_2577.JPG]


In this case, the LEDs sit underneath the keyswitch. Therefore one must attach the LEDs now.

#### Step 3.3.1
Thread the LEDs through their mounting holes. The orientation matters this time, so make sure the longer lead threads through the circular hole, while the shorter lead threads through the square hole. Sparkfun has guide about LED orientation which you can read [here](https://learn.sparkfun.com/tutorials/light-emitting-diodes-leds/all):

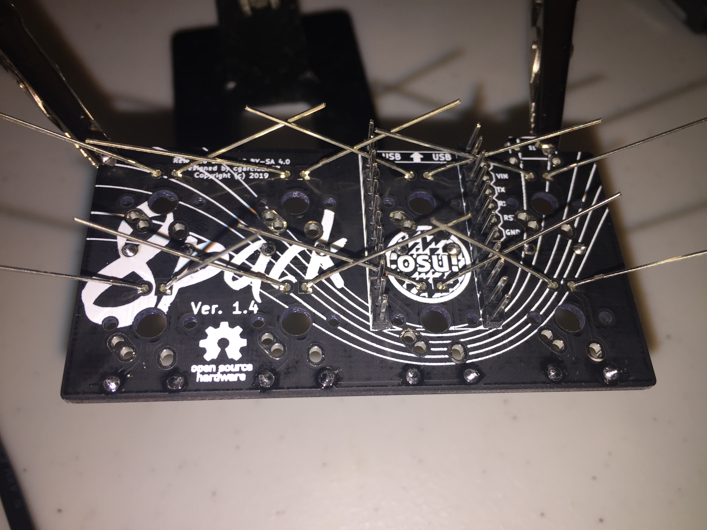
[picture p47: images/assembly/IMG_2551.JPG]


#### Step 3.3.2
Solder the LEDs and trim their leads:

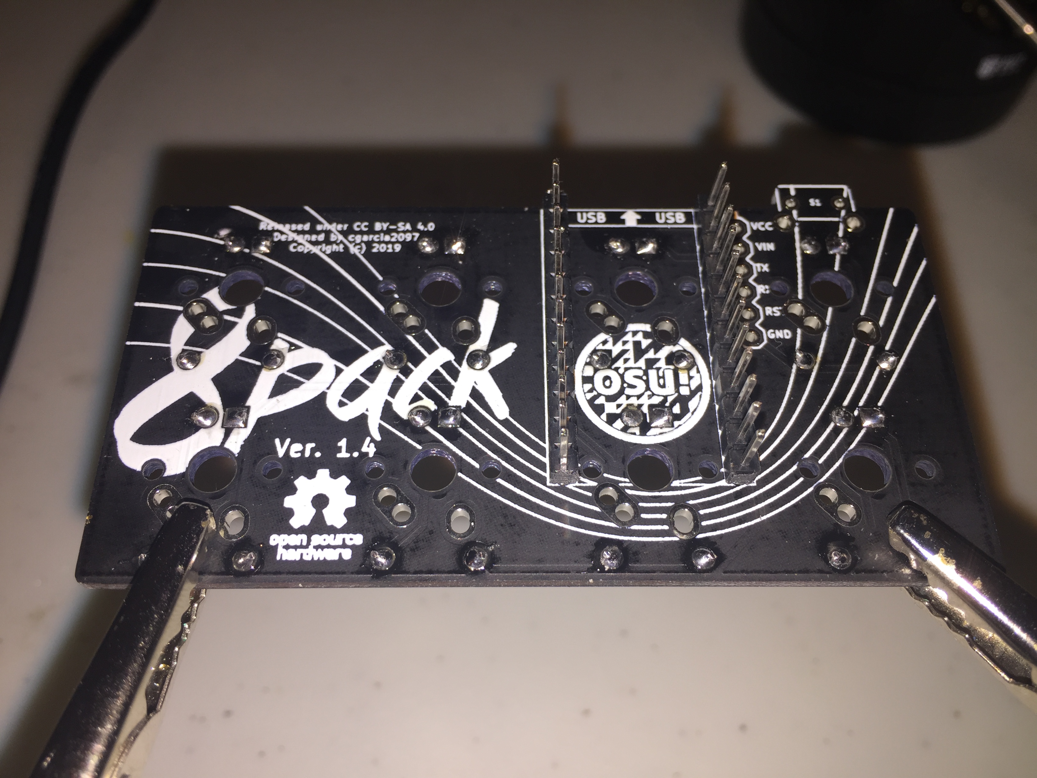
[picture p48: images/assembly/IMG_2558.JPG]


### Using a Cherry-style switch
A Cherry-style switch is characterized by a cross pattern only.



In this case the switch sits on top of the keyswitch. Steps 3.3.1 to 3.3.2 must wait after the top plate has been joined with the PCB.

## Step 3.4 - Attach reset button
### Step 3.4.1
Attach the pushbutton as shown down below:

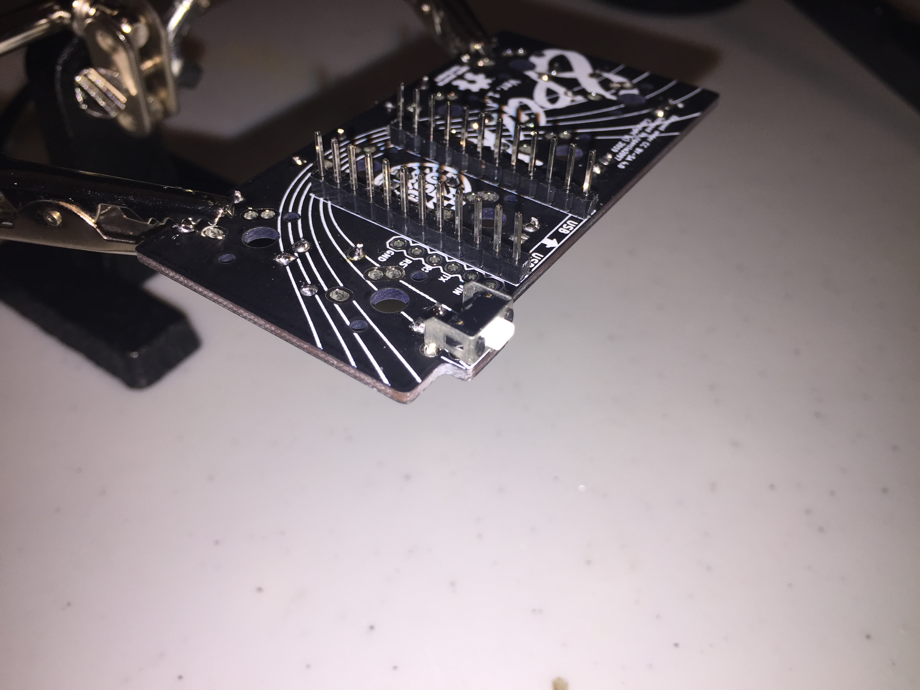
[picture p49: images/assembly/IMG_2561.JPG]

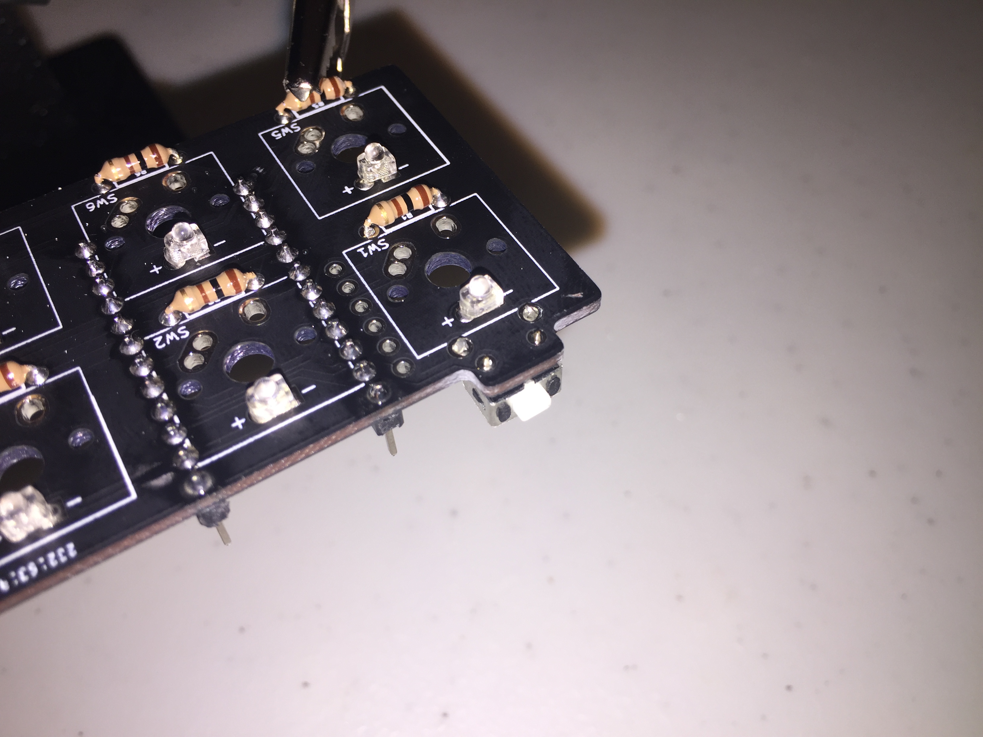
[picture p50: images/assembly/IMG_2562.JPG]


### Step 3.4.2
Solder the pushbutton to the PCB

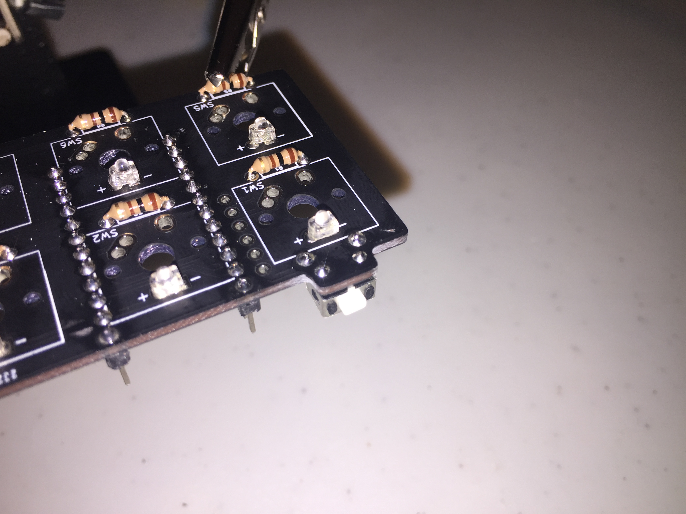
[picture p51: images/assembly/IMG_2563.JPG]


# Step 4 - Join top plate and PCB together
## Step 4.1 - Solder the other end of the top plate wire - (For underglow use. skip if unneeded)
### Step 4.1.1
Strip the other end of the wires.

### Step 4.1.2
Attach the wires to their designated locations
* Red to VCC
* Black to GND
* Yellow to RX

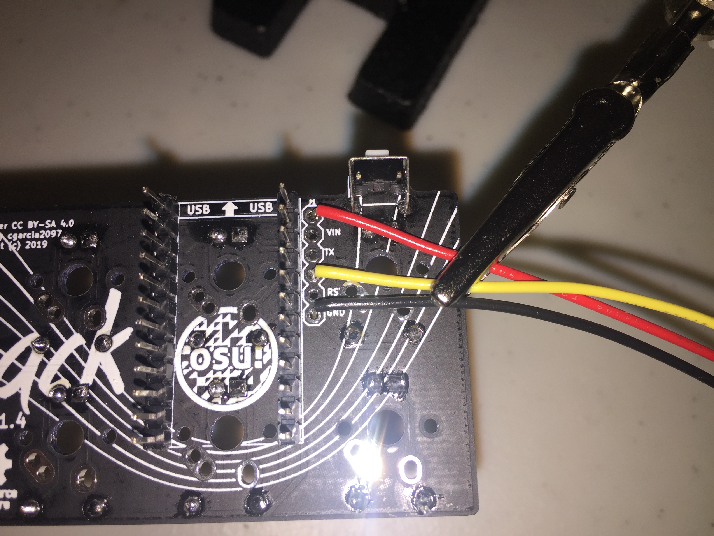
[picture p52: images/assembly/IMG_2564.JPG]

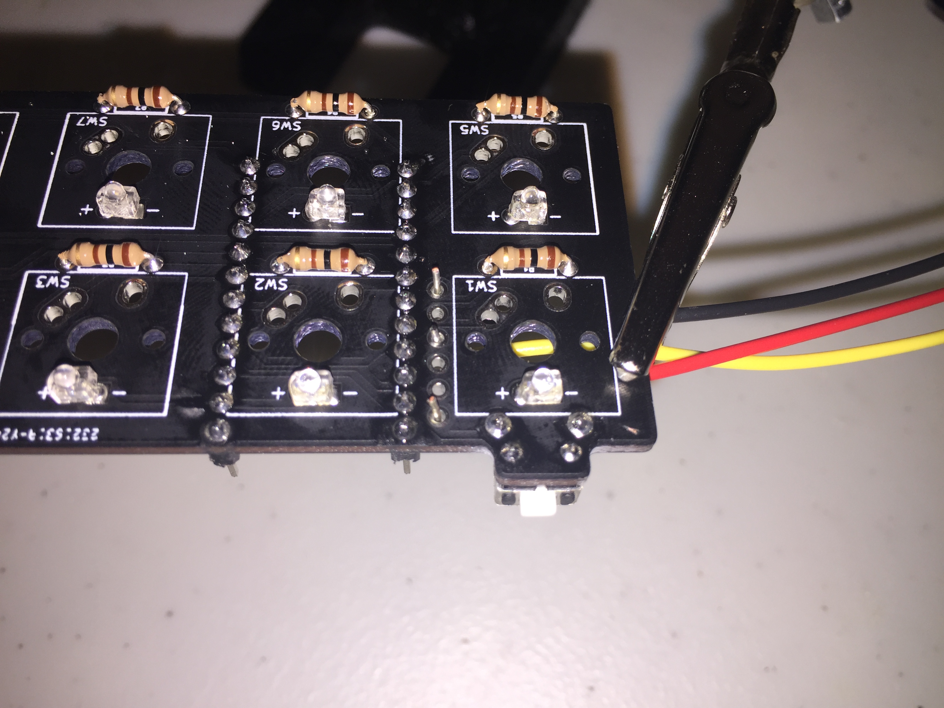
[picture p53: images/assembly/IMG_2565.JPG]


### Step 4.1.3
Solder and trim the wires in place:
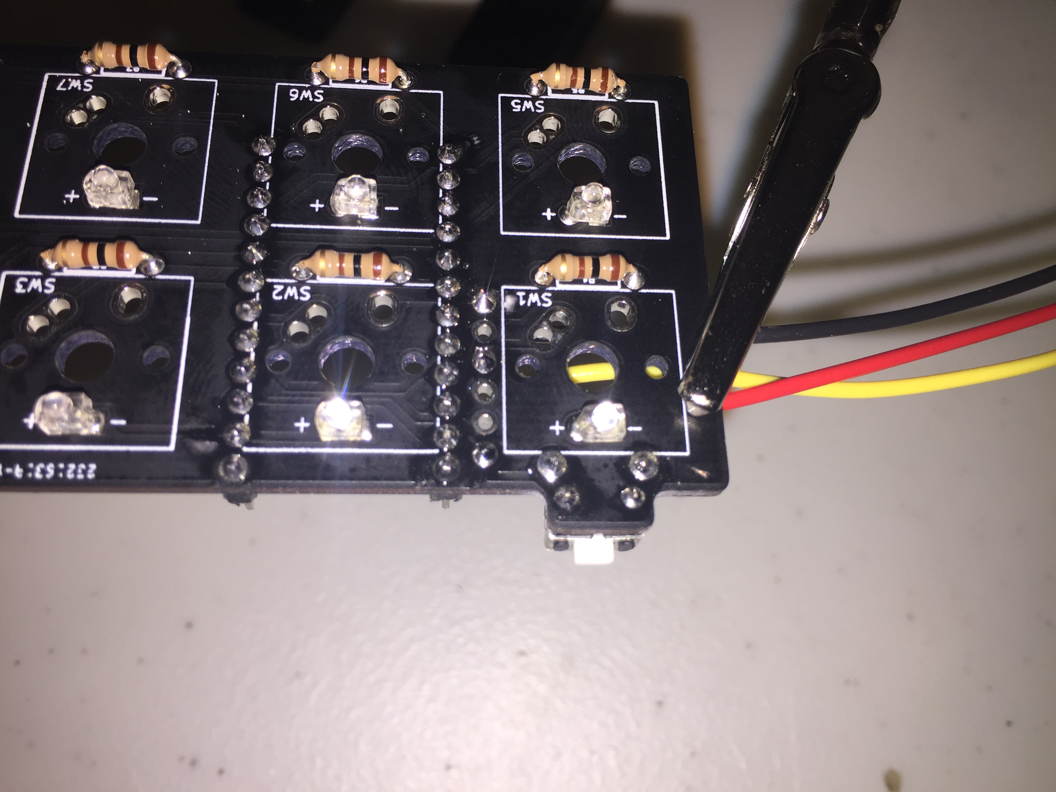
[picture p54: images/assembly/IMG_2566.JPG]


## Step 4.2 - Attach switches to PCB
Align the switch pins to the PCB holes, press and hold the PCB down and solder the switches in place:

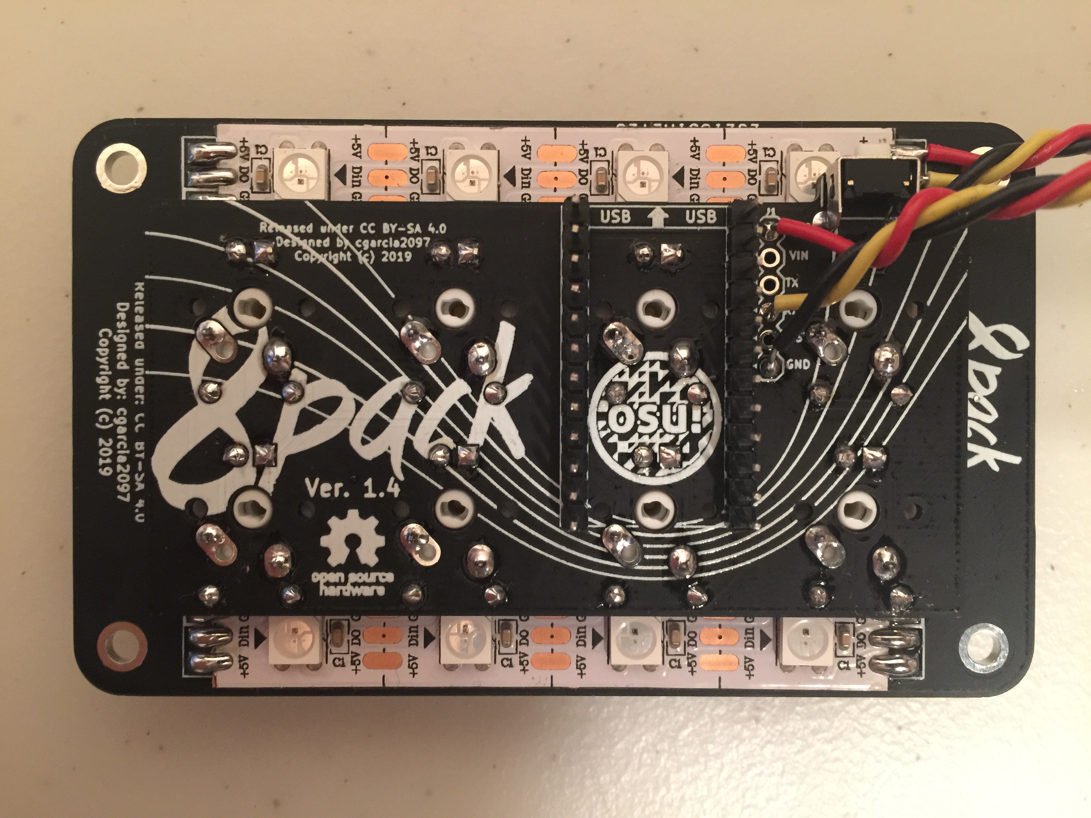
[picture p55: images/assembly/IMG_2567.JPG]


# Step 5 - Attach the microcontroller

## Caution: 

Depending on the revision of the PCB used, the orientation differs. As such, Ver. 1.2 and lower use this orientation (USB port faces away form PCB and south relative to the 8pack logo):

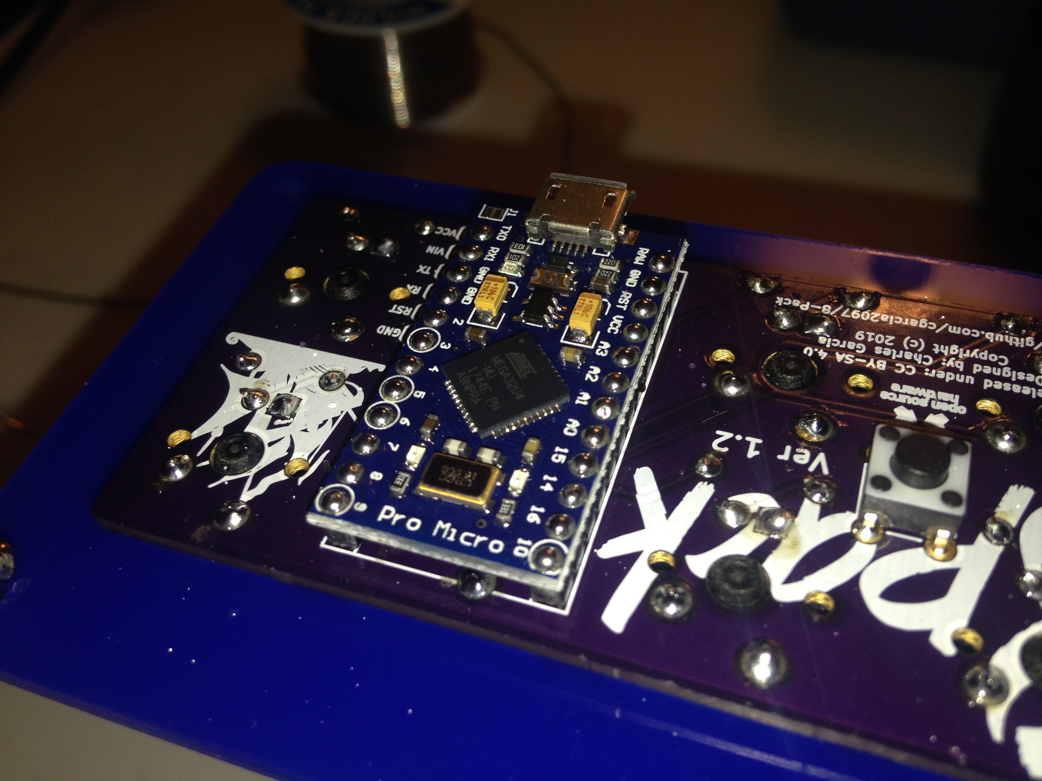
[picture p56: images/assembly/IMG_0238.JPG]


While Ver. 1.3 and above use this orientation (USB port faces towards the PCB and north relative to the 8pack logo):

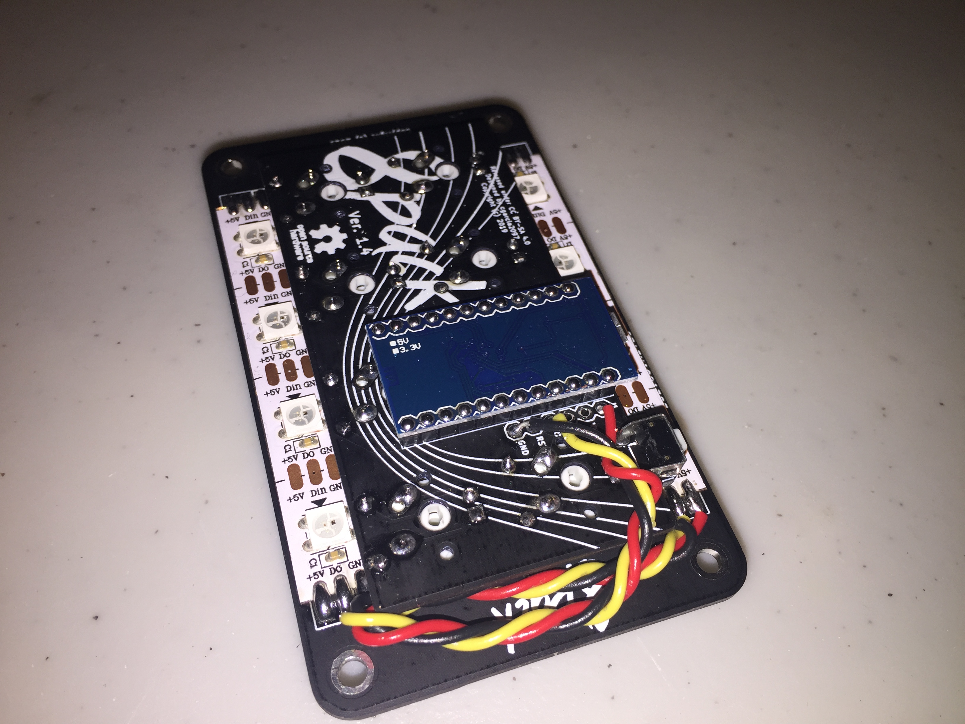
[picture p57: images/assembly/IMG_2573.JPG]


## Step 5.1 
Slot the Pro Micro through the headers

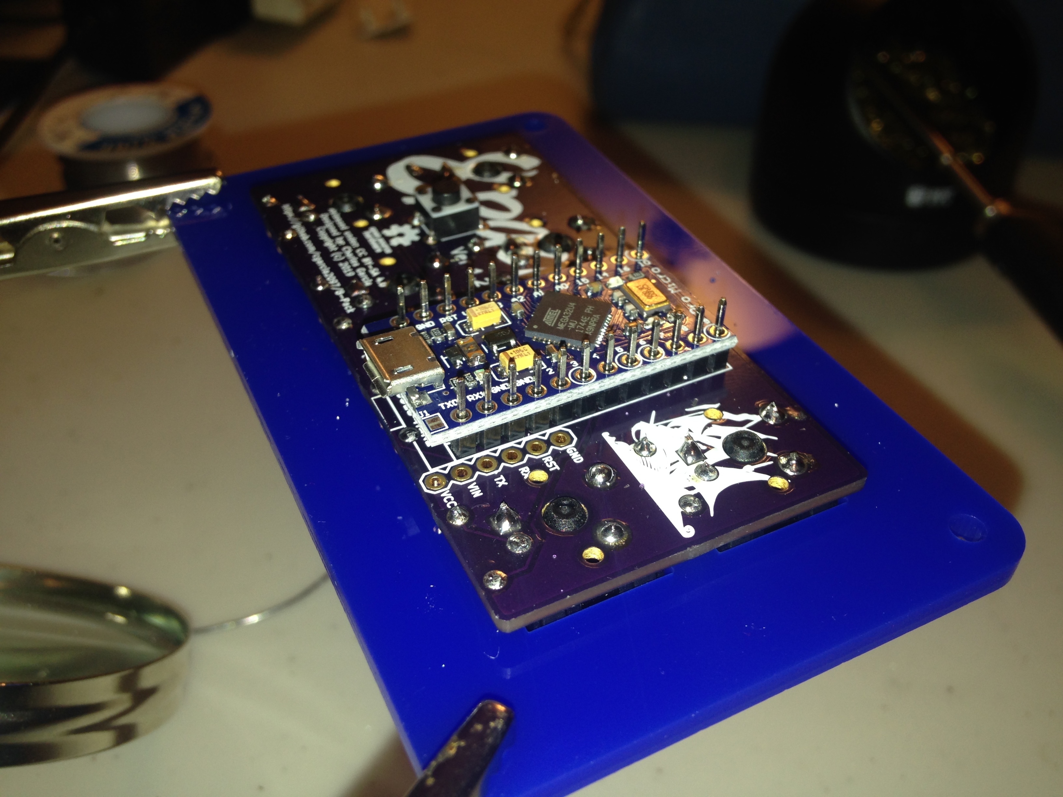
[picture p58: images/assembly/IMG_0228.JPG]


## Step 5.2 
Trim the headers

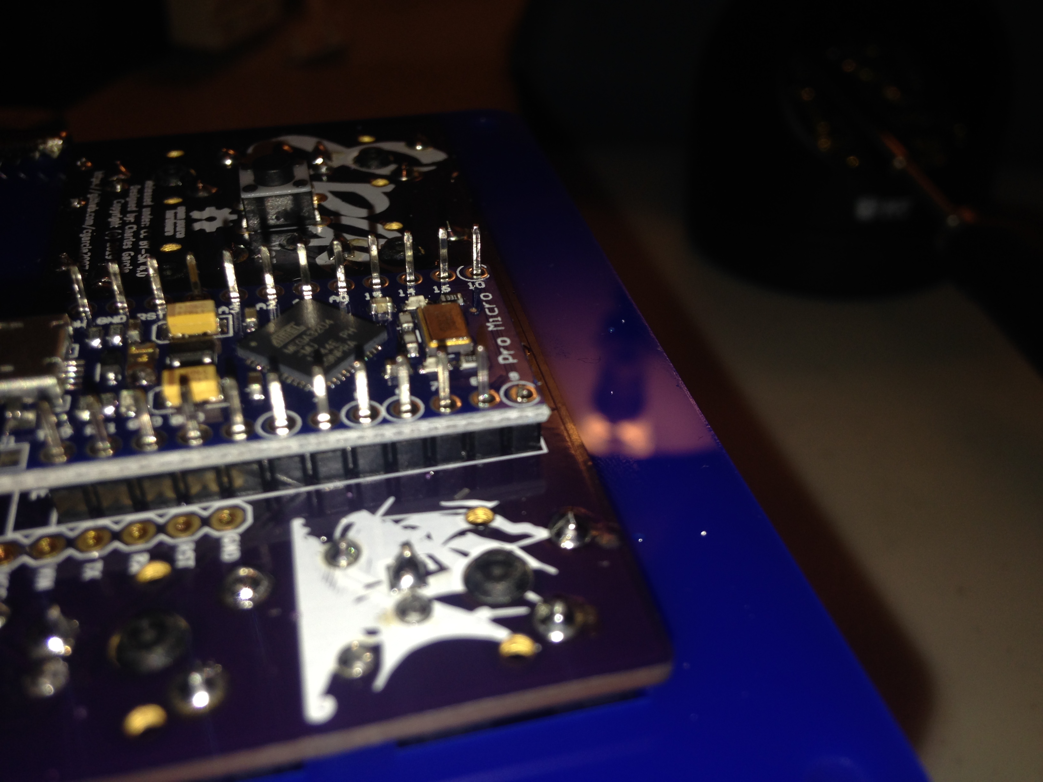
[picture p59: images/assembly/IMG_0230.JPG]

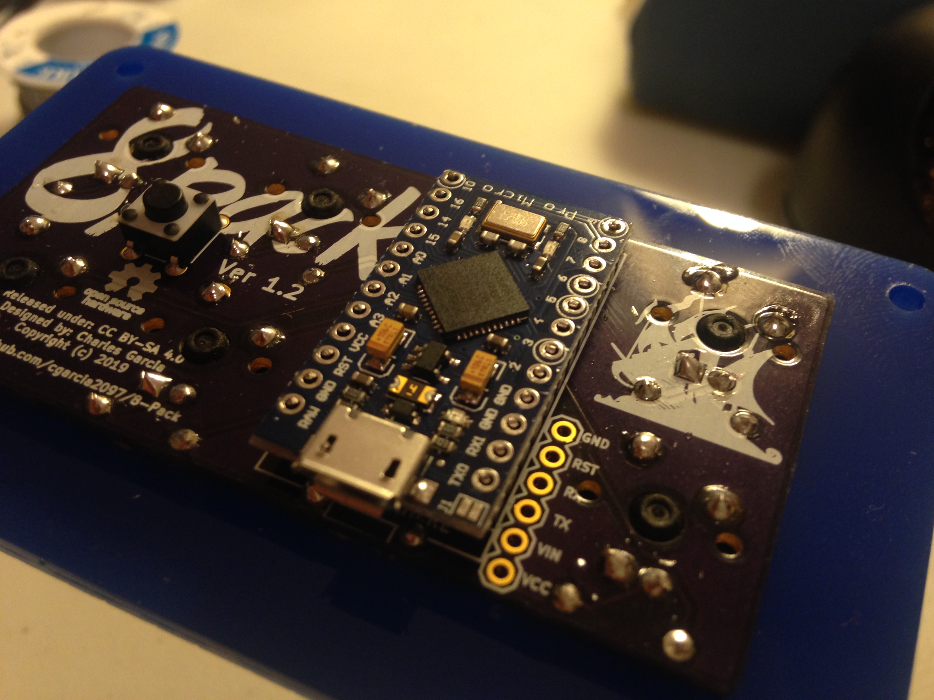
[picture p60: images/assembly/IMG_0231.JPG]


## Step 5.3
Solder the headers as shown below

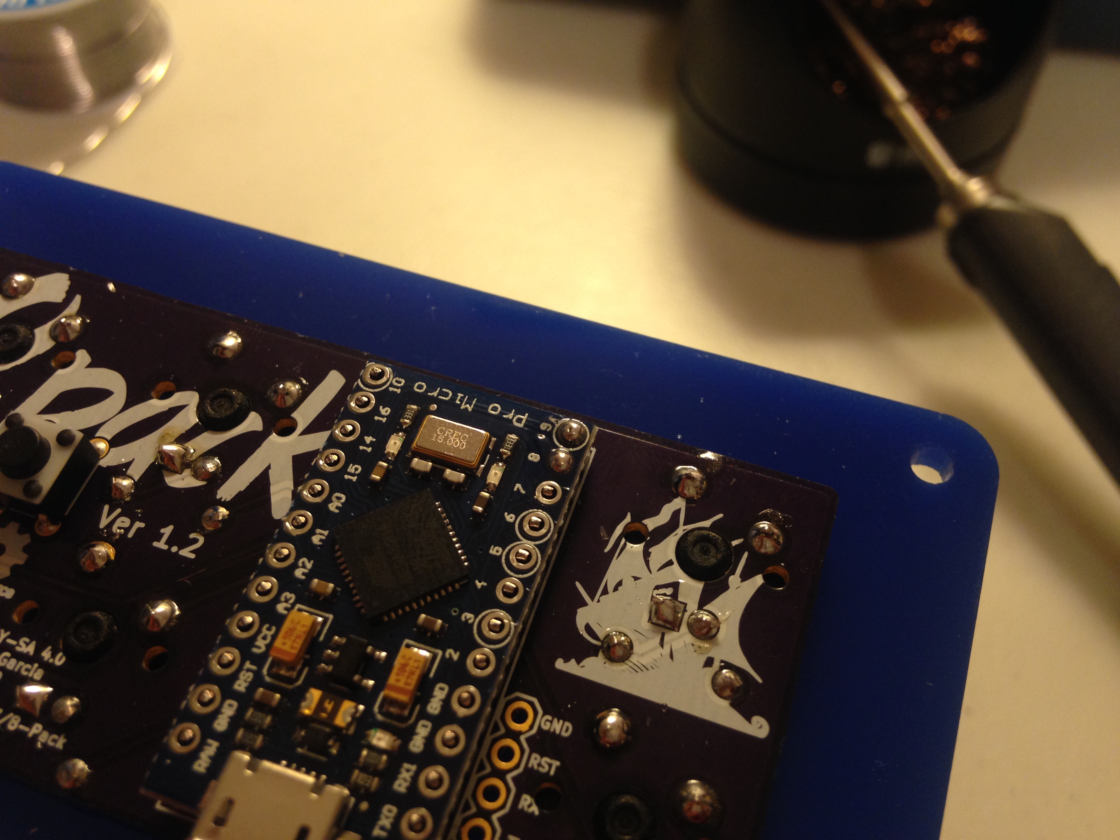
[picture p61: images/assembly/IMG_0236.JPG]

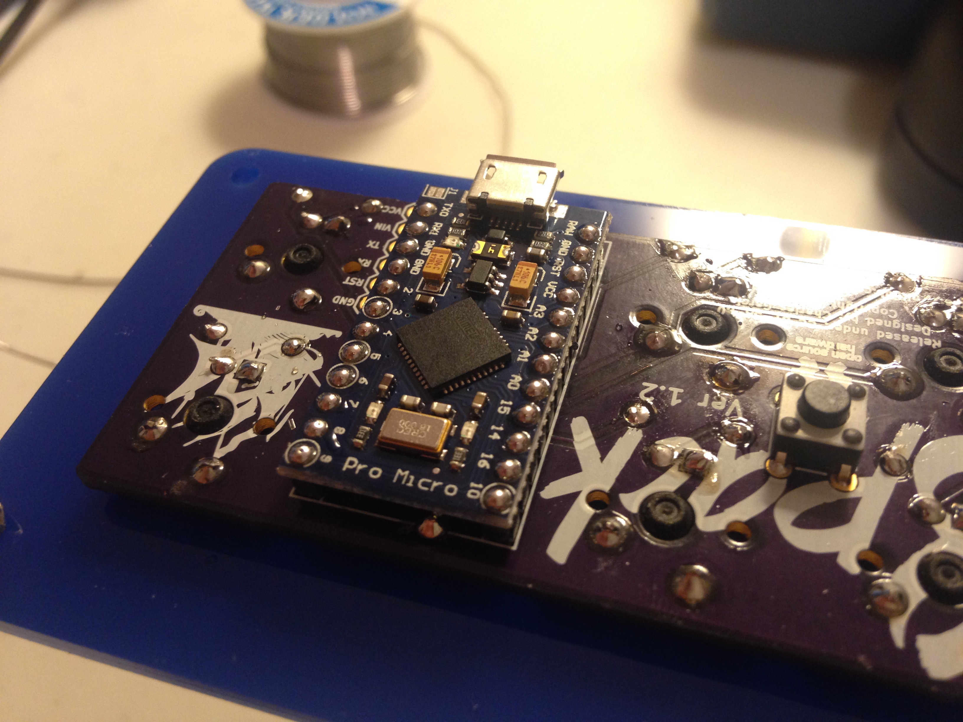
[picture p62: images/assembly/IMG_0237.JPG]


# Step 6 - Program the board
Head over to the [Programming section](./PROGRAMMING.md) for this section of the guide.

# Step 7 - Attach the bottom plates
With the included M3 standoffs and bolts, attach the bottom plate to the top plate

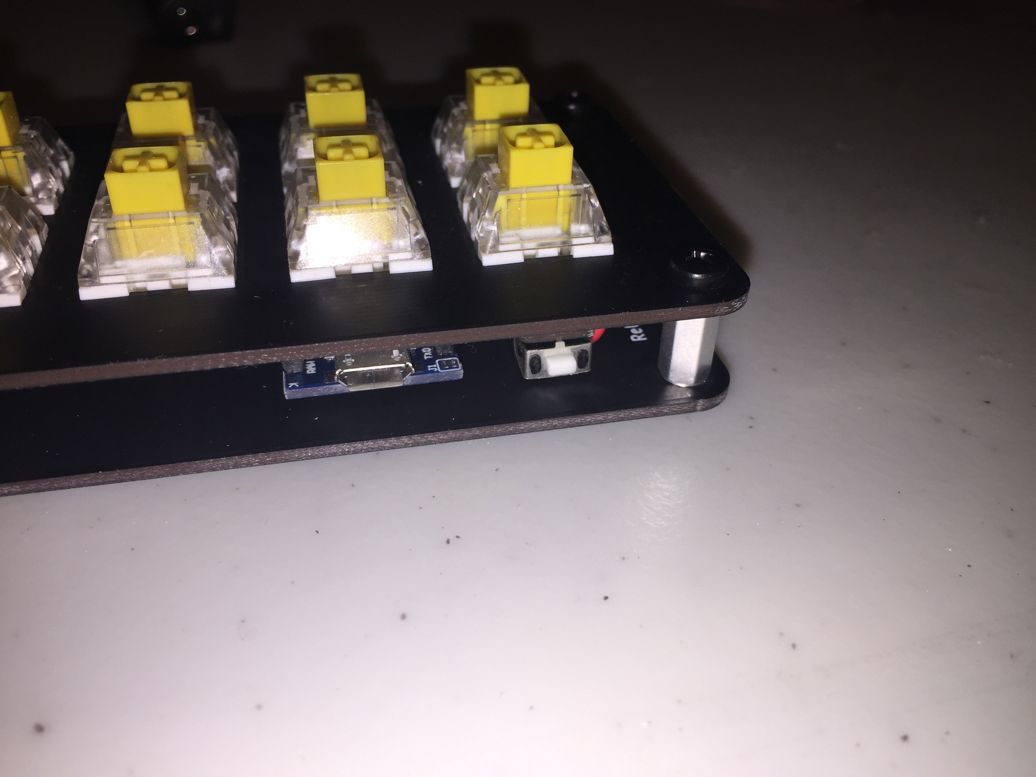
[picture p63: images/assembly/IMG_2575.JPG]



Voila, you now have a working keypad, ready for a set of keycaps.

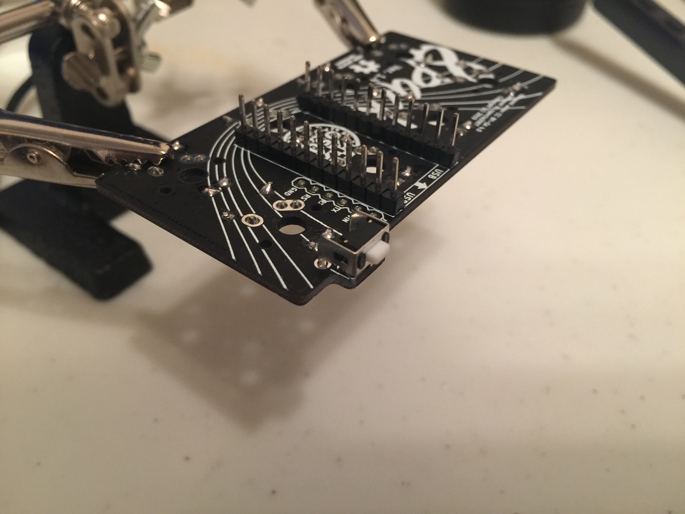
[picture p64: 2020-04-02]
images/assembly/IMG_2560.JPG

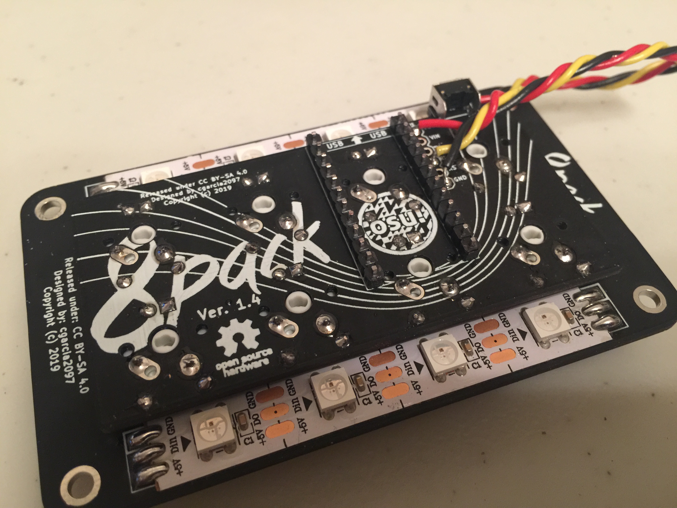
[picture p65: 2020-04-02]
images/assembly/IMG_2569.JPG

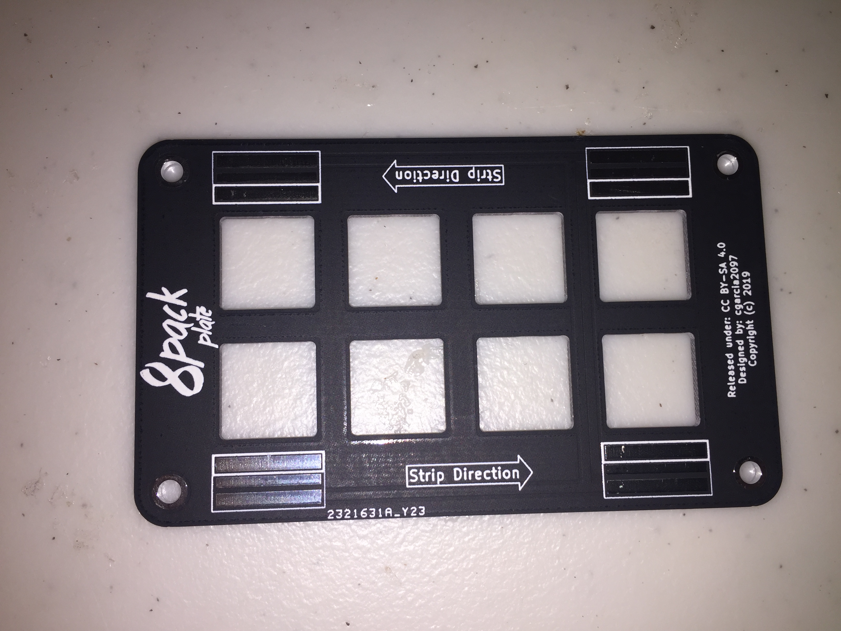
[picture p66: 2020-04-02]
images/assembly/IMG_2524.JPG

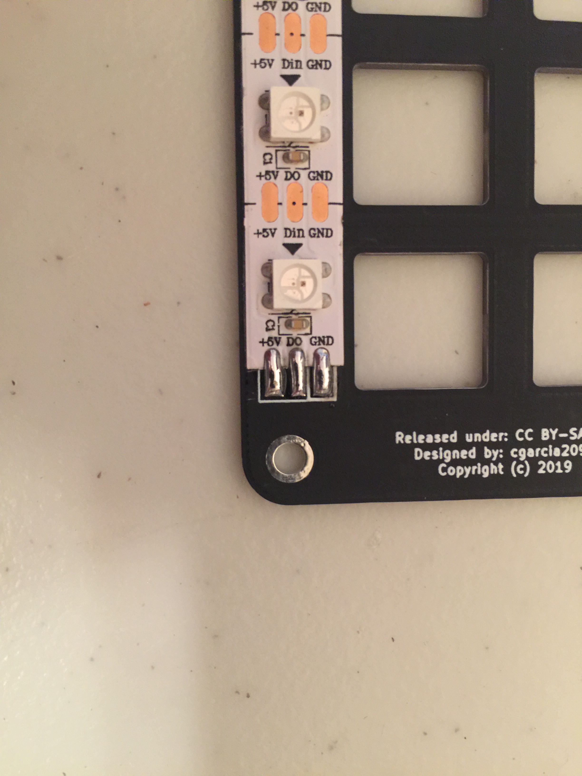
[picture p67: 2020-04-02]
images/assembly/IMG_2532.JPG

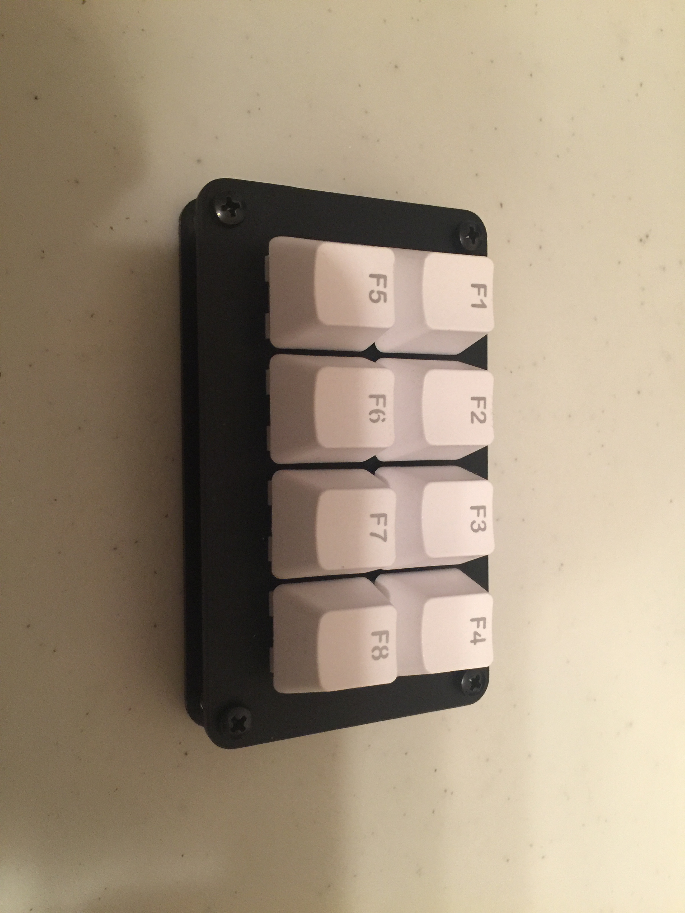
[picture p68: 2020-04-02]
images/assembly/IMG_2581.JPG

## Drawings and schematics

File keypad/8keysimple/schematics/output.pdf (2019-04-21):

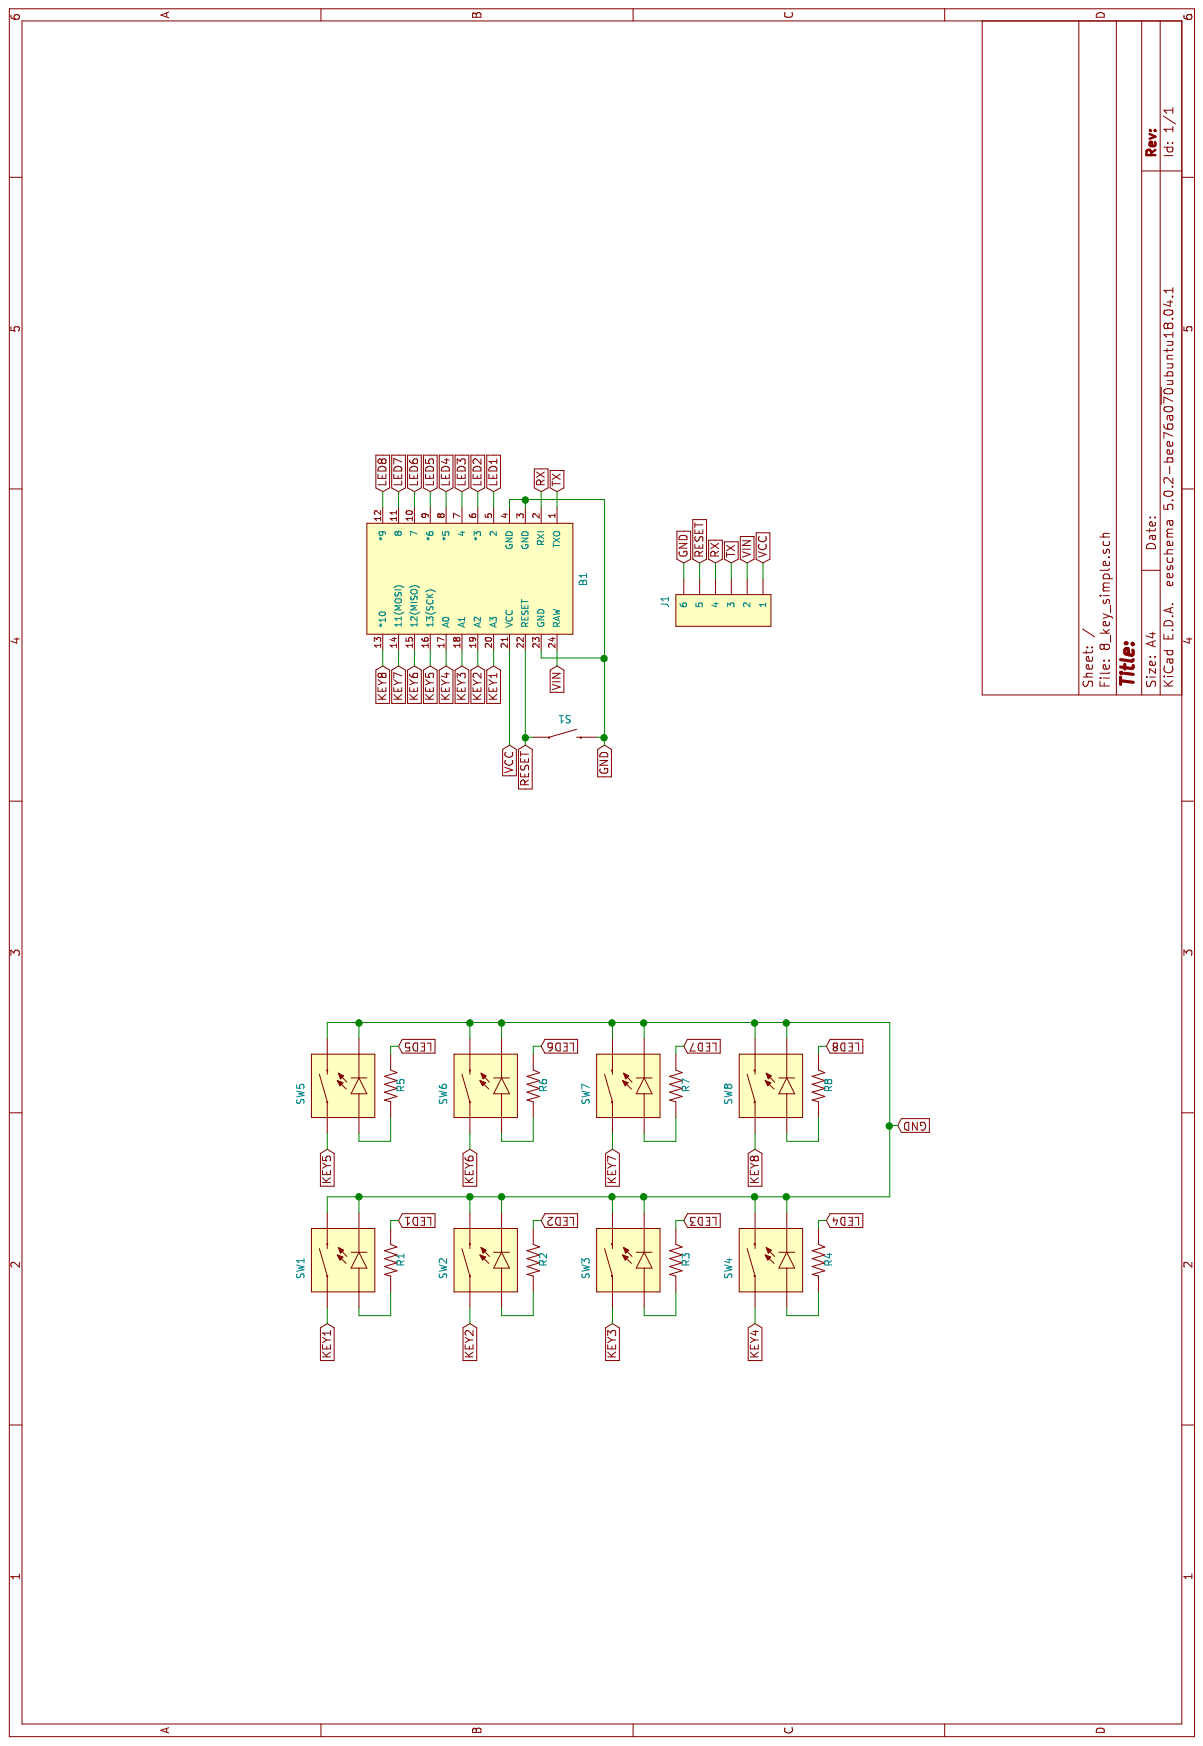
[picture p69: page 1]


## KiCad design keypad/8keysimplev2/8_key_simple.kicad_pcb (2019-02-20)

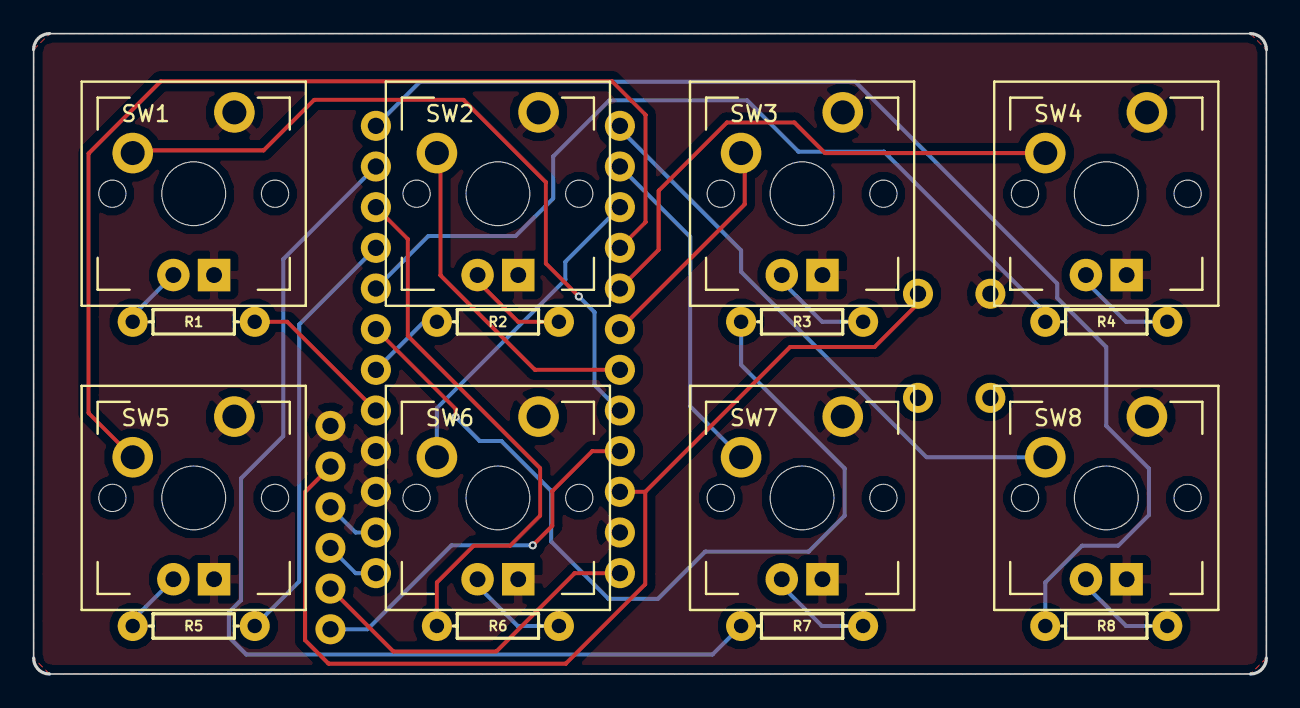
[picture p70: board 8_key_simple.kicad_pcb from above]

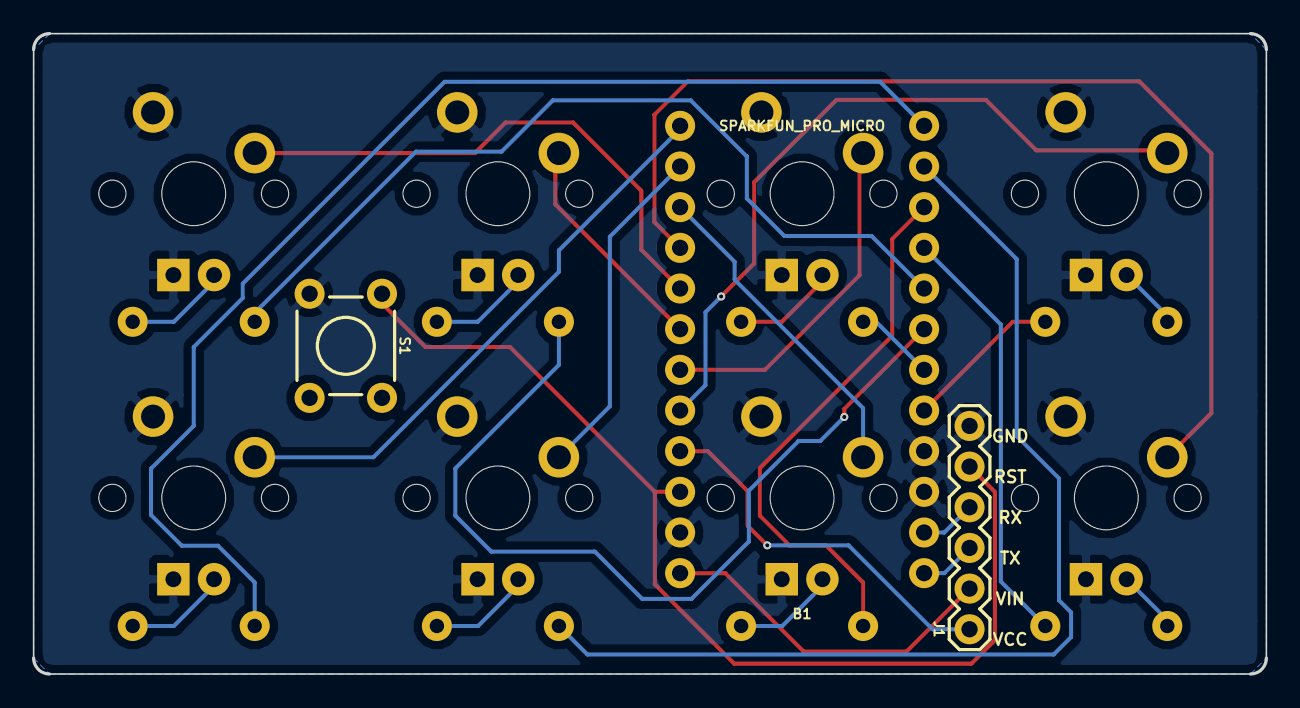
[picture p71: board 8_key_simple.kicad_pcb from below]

Board: 2 copper layers, 77.0 x 40.0 mm, 19 parts (3 on the bottom side), 30 nets.

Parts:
B1: SPARKFUN_PRO_MICRO
J1: CONN_06NO_SILK_FEMALE_PTH; 1X06
R1, R2, R3, R4, R5, R6, R7, R8: RESISTORAXIAL-0.3; AXIAL-0.3
S1: MOMENTARY-SWITCH-SPST-PTH-6.0MM; TACTILE_SWITCH_PTH_6.0MM
SW1, SW2, SW3, SW4, SW5, SW6, SW7, SW8: MOMENTARY-SWITCH-SPST-LED-PTH-CHERRY; MX_LED

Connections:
GND: B1.3, B1.4, B1.23, J1.6, S1.3, SW1.K, SW1.S2, SW2.K, SW2.S2, SW3.K, SW3.S2, SW4.K, SW4.S2, SW5.K, SW5.S2, SW6.K, SW6.S2, SW7.K, SW7.S2, SW8.K, SW8.S2
KEY1: B1.20, SW1.S1
KEY2: B1.19, SW2.S1
KEY3: B1.18, SW3.S1
KEY4: B1.17, SW4.S1
KEY5: B1.16, SW5.S1
KEY6: B1.15, SW6.S1
KEY7: B1.14, SW7.S1
KEY8: B1.13, SW8.S1
LED1: B1.5, R1.P$1
LED2: B1.6, R2.P$1
LED3: B1.7, R3.P$1
LED4: B1.8, R4.P$1
LED5: B1.9, R5.P$1
LED6: B1.10, R6.P$1
LED7: B1.11, R7.P$1
LED8: B1.12, R8.P$1
unnamed: R1.P$2, SW1.A
unnamed: R2.P$2, SW2.A
unnamed: R3.P$2, SW3.A
unnamed: R4.P$2, SW4.A
unnamed: R5.P$2, SW5.A
unnamed: R6.P$2, SW6.A
unnamed: R7.P$2, SW7.A
unnamed: R8.P$2, SW8.A
RESET: B1.22, J1.5, S1.1
RX: B1.2, J1.4
TX: B1.1, J1.3
VCC: B1.21, J1.1
VIN: B1.24, J1.2

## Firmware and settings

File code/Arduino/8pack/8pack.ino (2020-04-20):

/*
  Copyright (c) 2019, Charles Garcia
  All rights reserved.
  Redistribution and use in source and binary forms, with or without
  modification, are permitted provided that the following conditions are met:
  1. Redistributions of source code must retain the above copyright notice, this
    list of conditions and the following disclaimer.
  2. Redistributions in binary form must reproduce the above copyright notice,
    this list of conditions and the following disclaimer in the documentation
    and/or other materials provided with the distribution.
  THIS SOFTWARE IS PROVIDED BY THE COPYRIGHT HOLDERS AND CONTRIBUTORS "AS IS" AND
  ANY EXPRESS OR IMPLIED WARRANTIES, INCLUDING, BUT NOT LIMITED TO, THE IMPLIED
  WARRANTIES OF MERCHANTABILITY AND FITNESS FOR A PARTICULAR PURPOSE ARE
  DISCLAIMED. IN NO EVENT SHALL THE COPYRIGHT OWNER OR CONTRIBUTORS BE LIABLE FOR
  ANY DIRECT, INDIRECT, INCIDENTAL, SPECIAL, EXEMPLARY, OR CONSEQUENTIAL DAMAGES
  (INCLUDING, BUT NOT LIMITED TO, PROCUREMENT OF SUBSTITUTE GOODS OR SERVICES;
  LOSS OF USE, DATA, OR PROFITS; OR BUSINESS INTERRUPTION) HOWEVER CAUSED AND
  ON ANY THEORY OF LIABILITY, WHETHER IN CONTRACT, STRICT LIABILITY, OR TORT
  (INCLUDING NEGLIGENCE OR OTHERWISE) ARISING IN ANY WAY OUT OF THE USE OF THIS
  SOFTWARE, EVEN IF ADVISED OF THE POSSIBILITY OF SUCH DAMAGE.
  The views and conclusions contained in the software and documentation are those
  of the authors and should not be interpreted as representing official policies,
  either expressed or implied, of the 8pack project.
*/

/**
  * File: main.cpp
  * Author: Charles Garcia
  * Date: June 11, 2019
  * Description: Main .cpp for the 8pack project
  *
*/

// Global libraries
#include <Arduino.h>

// Project-specific Libraries
#include "button.h"
#include "backlight.h"
#include "underglow.h"
#include "keys.h"

// Timing variable
uint32_t curTime = 0, prevTime = 0;

/**
 * @brief   8pack setup functions
 * @params  None
 * @returns None
 */
 void setup(){
  // Initialize serial 
  Serial.begin(115200);

  // Initialize buttons
  buttonSetup();

  // Initialize underglow
  underglowSetup();
  underglowStartAnimation(125);

  // Initialize backlighting
  backlightSetup();
  backlightStartAnimation(75);
}

/**
 * @brief   8pack main function
 * @params  None
 * @returns None
 */
 void loop(){
   uint8_t prevState = buttonStates;
   curTime = millis();

  // Scan buttons
  buttonScan();
  
  // Send keypresses upon change in buttonState
  if(prevState != buttonStates){
      sendKeyPress(buttonStates);
  }

  // Lighting section
  underglowMainAnimation(buttonStates);
 }

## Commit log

2019-02-20 Added version 1.1 of PCB
    [8_key_simple_noschem.sch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]
2019-03-05 Added rough BOM. Does not include cost of cases
    [BOM Keyboard Workshop 2019.xlsx]
2019-03-11 Uploaded Case Files and Assembly Images
    [Base.stl, Plate.stl, c652d3e98de1d1b4dfcd3dc86a30a444346ce92a_bottom.dxf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]
2019-03-29 Added new plates update
2019-03-29 Added plate version 1.0
    [8-key-bottom-plate-1.0.kicad_pcb, 8-key-top-plate-1.0.kicad_pcb, neopixel_plates.sch]
2019-03-31 Added zip files for ordering PCBs online
    [8keyv2-B.Cu.gbr, 8keyv2-B.Mask.gbr, 8keyv2-B.Paste.gbr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]
2019-03-31 Added example for use with the underglow plates
2019-03-31 Consolidated keypad PCB files
    [8_key_simple.kicad_pcb, 8_key_simple.sch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]
2019-03-31 Fixed links for downloading gerber files
2019-04-16 Create ASSEMBLY GUIDE
2019-04-17 Update ASSEMBLY GUIDE
2019-04-17 Rename ASSEMBLY GUIDE to ASSEMBLY
2019-04-21 Added libraries and Ver 1.2
    [8-key-bottom-plate-1.0.kicad_pcb, 8-key-top-plate-1.0.kicad_pcb, 8_key_simple.kicad_pcb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]
2019-04-28 Included Arduino steps
2020-04-02 Restructured project repository
    [8-key-bottom-1.2.kicad_pcb, 8-key-bottom-plate-1.0.kicad_pcb, 8-key-top-plate-1.0.kicad_pcb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]
2020-04-02 Updated Assembly.md
2020-07-07 Updated ASSEMBLY and UPDATES

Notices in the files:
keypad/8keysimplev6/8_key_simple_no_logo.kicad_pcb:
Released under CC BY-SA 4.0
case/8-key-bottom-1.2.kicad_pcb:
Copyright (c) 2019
